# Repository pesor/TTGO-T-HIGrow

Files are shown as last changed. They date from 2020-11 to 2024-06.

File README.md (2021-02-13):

# LilyGO TTGO T-HiGrow
## TTGO T-HIGrow MQTT autodiscover interface for Homeassistant

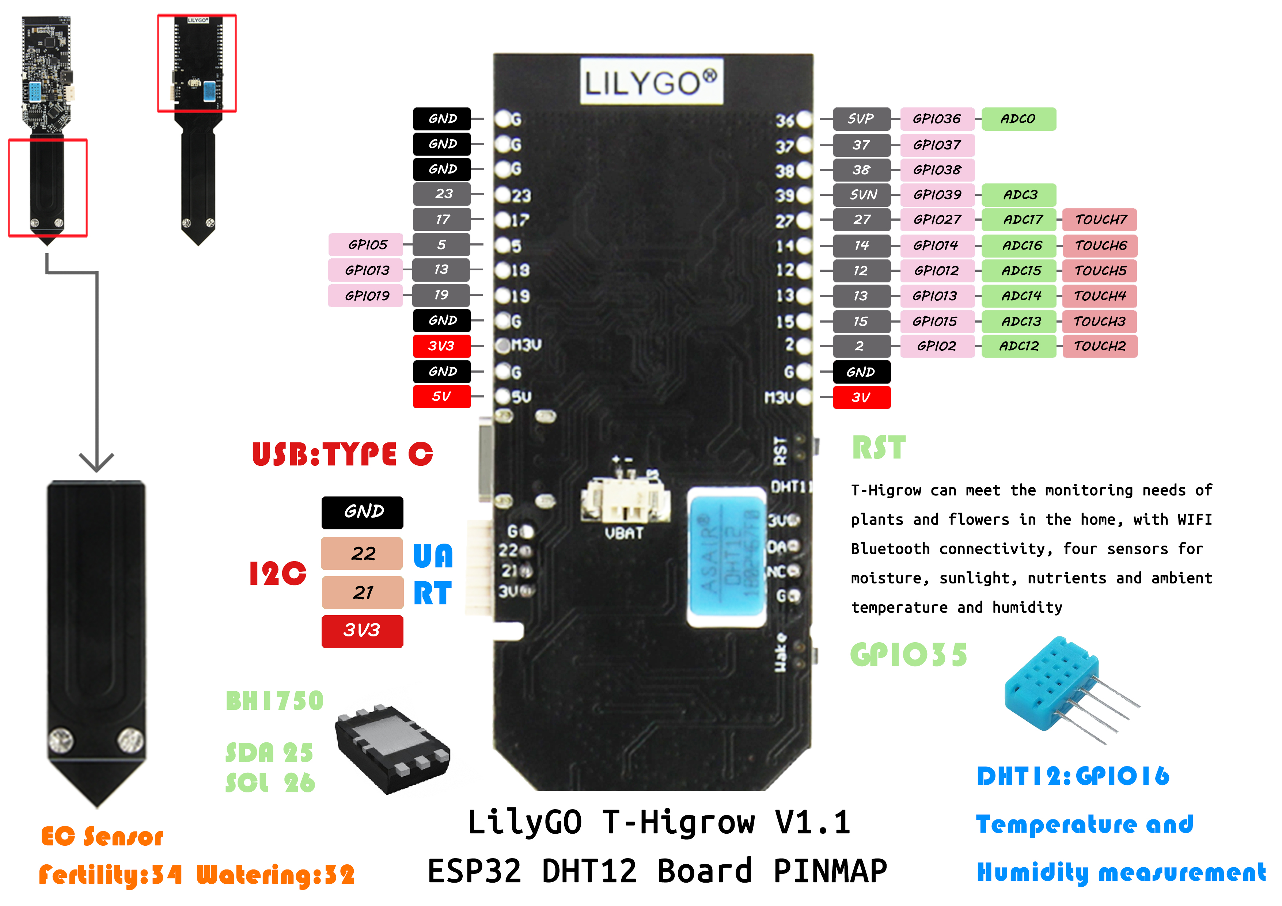
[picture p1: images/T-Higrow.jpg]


     


### Getting started

Go to the [WIKI](https://github.com/pesor/TTGO-T-HIGrow/wiki) of this Repo, there you will find a comprehensive toturial to help you implement this card.

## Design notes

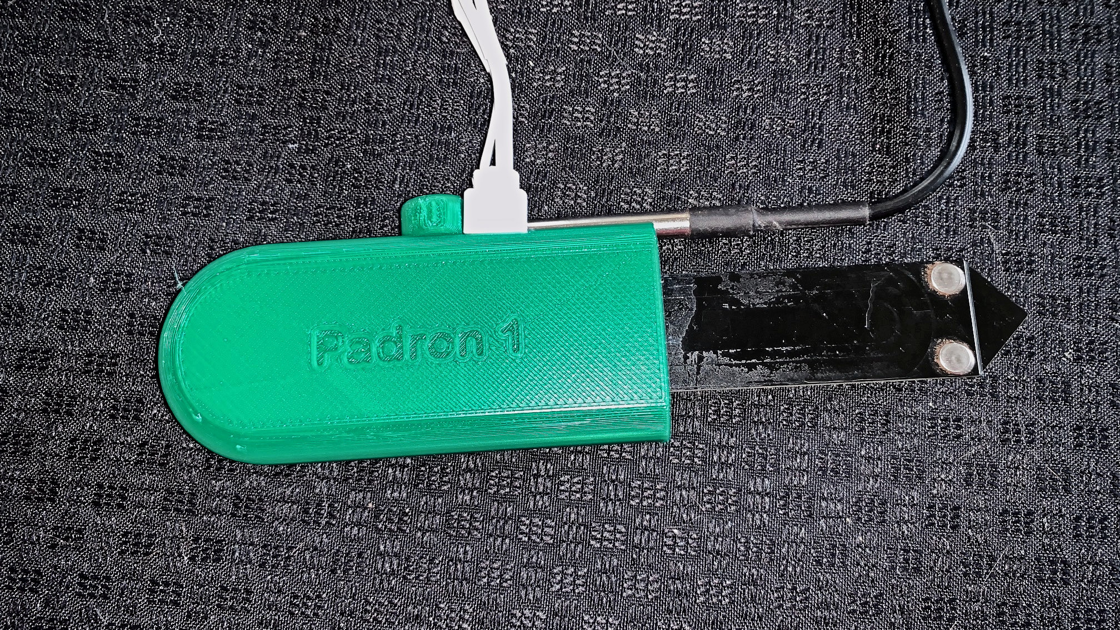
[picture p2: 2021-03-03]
images/CaseSoilTempTop.jpg

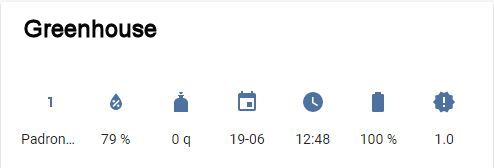
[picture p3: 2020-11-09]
images/Green-house.jpg

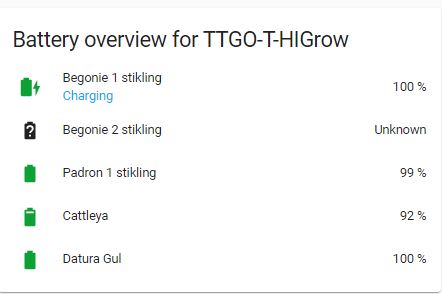
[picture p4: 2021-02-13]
images/battery-state-card-view.JPG

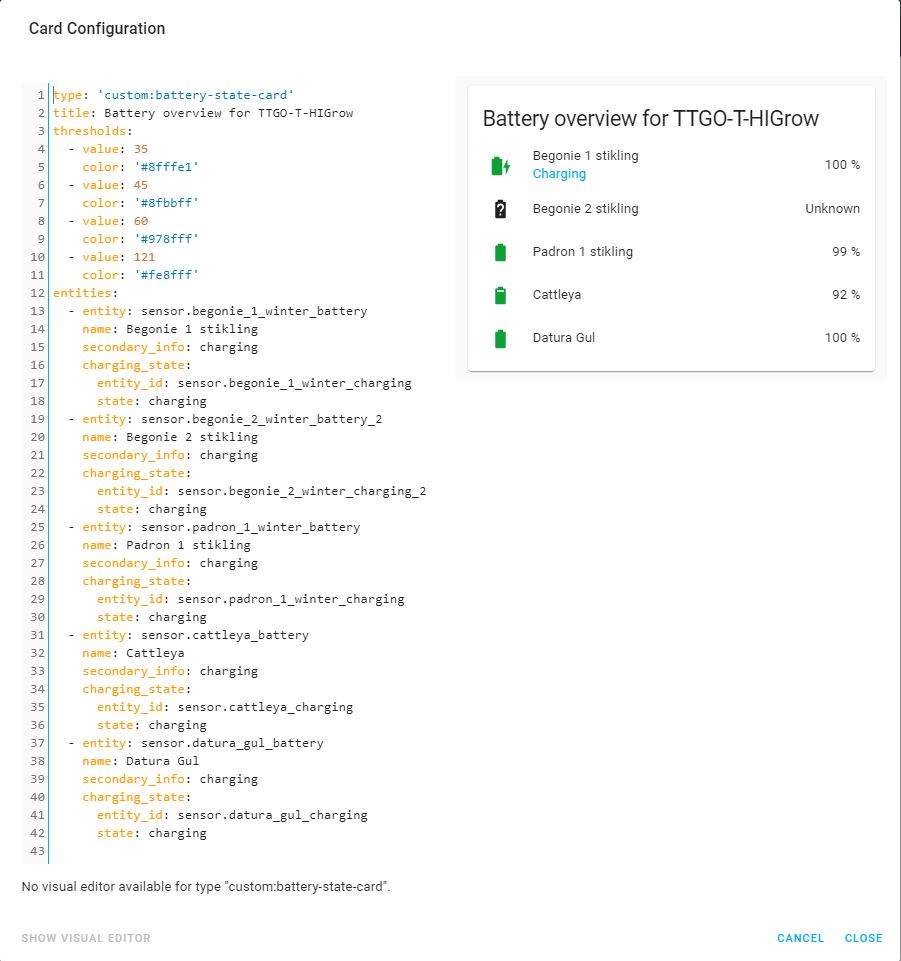
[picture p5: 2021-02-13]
images/battery-state-card.JPG

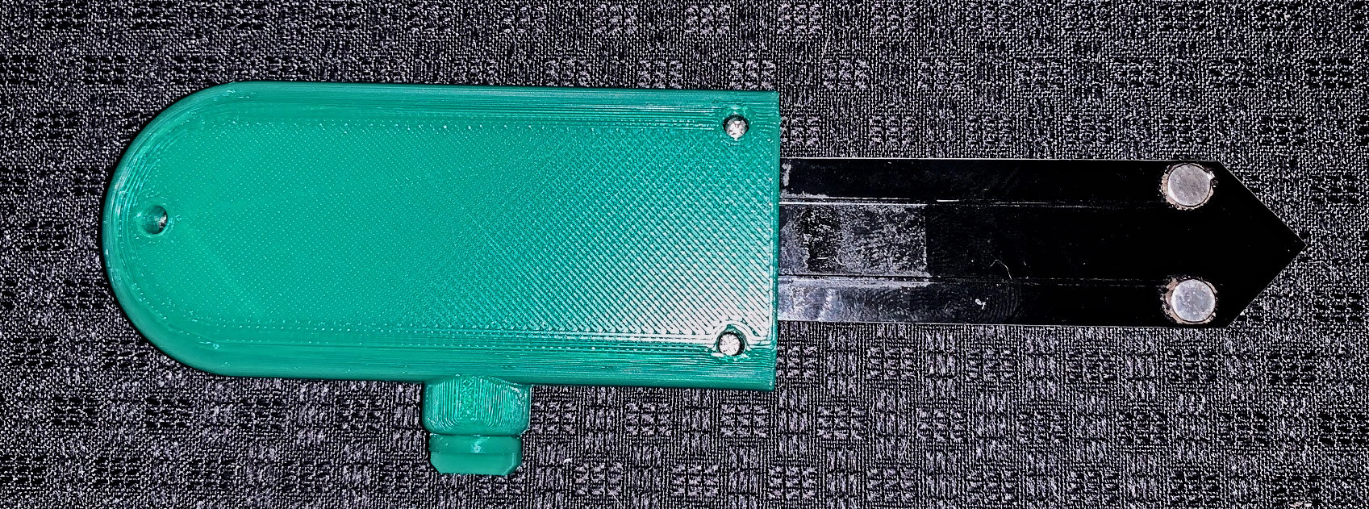
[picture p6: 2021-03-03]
images/CaseSoilBottom.jpg

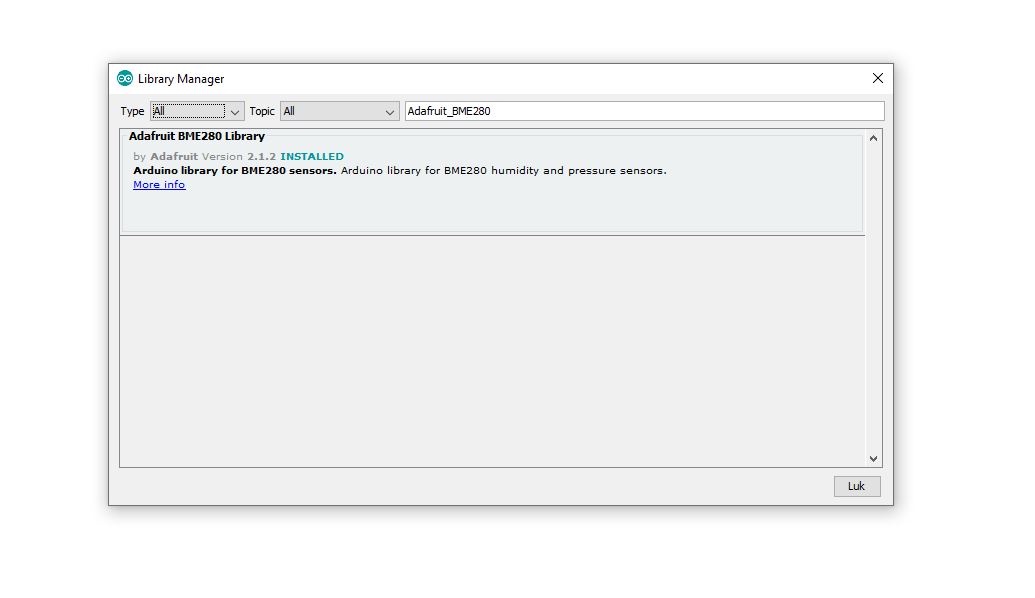
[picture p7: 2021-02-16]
images/BME280.JPG

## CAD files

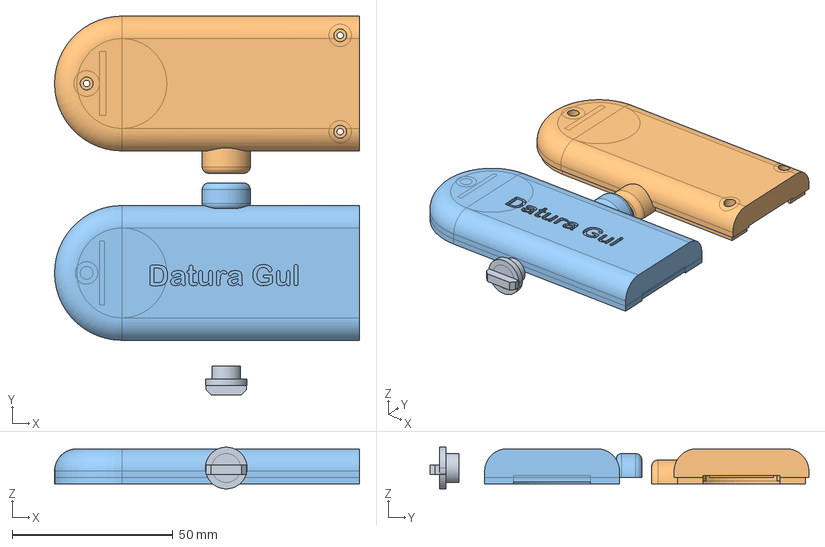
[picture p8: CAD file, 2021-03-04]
Casing/ClosedBatteryCase.FCStd
95.0 x 118.0 x 13.0 mm
Knot
Buttom
Top001

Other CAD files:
Casing/ClosedBatterySoilSensorCase.FCStd
Casing/ClosedBatteryCase.stl
Casing/ClosedBatterySoilSensorCase.stl

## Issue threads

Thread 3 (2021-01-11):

TTGO HiGrow with BME280

leeandy1, 2021-01-11:
I have just picked up 2 HiGrow boards and both have BME280 sensors onboard which are reporting null values. Both a version 1.1 boards 19-8-22.

How do I get these sensors to report values?

pesor, 2021-01-11:
There are no BME280 sensors on the boards, in the original program from LILYGO they referenced the BME280, but it is not there.

The code now have taken that into account, and therefore it will not (and cannot) report data from a nonexisting BME280.

leeandy1, 2021-01-11:
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

Thanks for the response. This is a picture of the board I have. As you can see there is no DHT11 sensor. I understand the BME280 sensor is circled in red? Please do correct me if I am wrong.

leeandy1, 2021-01-12:
Just to confirm firmware V4.0.6 appears to all function correctly for all other sensors. I currently have the board running to test battery life and will report back. I purchased the full kit with housing and battery. I am happy to assist with any testing you require but would advise I am fairly new to this.

pesor, 2021-01-12:
I will look into this.

The DHT sensor is discontinued, so I will order one with this sensor, and correct the coding to include BME280 also.

pesor, 2021-01-12:
I have just ordered on module from AliExpress, will amend coding when received.

leeandy1, 2021-01-12:
That's great to hear. If you need any help testing give me a shout.

pesor, 2021-01-12:
I also have ordered the BME280 chip it self, in order to try to solder it onto the board.

There are som confusing in the naming, some Call it BEM280, others Call it BME280, anyone knows why?

pesor, 2021-01-12:
@leeandy1 thanks for confirming, that the boards works with the soil and salt sensor.

leeandy1, 2021-01-12:
@pesor I believe it is a BME280, not sure why some people call it a BEM280 - maybe a typo?

My board has currently been running for 16 on a 200mAh battery and is reporting 97% left using your sleep settings. I need to take a look at boot count and sleep count as I think these are mixed up somehow. Boot count is 16 but sleep count is 0. Does your sleep routine effectively make the board boot each time it comes out of sleep?

pesor, 2021-01-12:
I have changed my interval to 3 hours om order to prolong the battery life.

Boot count is everytime the module starts normally after a normal deepSleep.

Sleep count, is when the module takes a 5 minutes DeepSleep, when something has gone wrong in the run. Like eg no network or mqtt connection. Zero is good, it should always be zero, otherwise the module do not run properly. The battery date counter does not work properly, I am working on that.

elecoq129, 2021-01-12:
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

On my side, I have order a pair DHT22 (white plastic packaging). I will do the soldering as soon as it arrives in replacement of the very cheap DHT11

pesor, 2021-01-12:
The DHT22 should work, if not, I will solder one (I have Them) to a module and check coding.

elecoq129, 2021-01-12:
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

I'm using the BootCount value and it works. However, the Sleep-Counter doesn't? But I'm still using an early firmware release.

elecoq129, 2021-01-12:
however I am still desperate to get the external  PT100 sensor using the DS18B20, but still missing the correct value template for mqtt broker. I have tried {{ value_json.DS18B20.Temperature }} but receive "unknow values" while all other values works. Could you please help?

pesor, 2021-01-12:
I am my self not totally sure if the sleep5counter works, as I have not yet seen a count > 0, i implemented it because I at a certain point had an unexplainable battery drain.

elecoq129, 2021-01-12:
>
>
> I am my self not totally sure if the sleep5counter works, as I have not yet seen a count > 0, i implemented it because I at a certain point had an unexplainable battery drain.

To be honest, not really needed, as bootCount is much enough

pesor, 2021-01-12:
> however I am still desperate to get the external PT100 sensor using the DS18B20, but still missing the correct value template for mqtt broker. I have tried {{ value_json.DS18B20.Temperature }} but receive "unknow values" while all other values works. Could you please help?

I do not know what you are referring to ?

leeandy1, 2021-01-12:
You can add an external sensor to the I2C UART port. I think the PT100 is just an external waterproof DS18b20 temperature and humidity sensor.

elecoq129, 2021-01-12:
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

The HiGrow board has en external (white) connector just below the USB-C, which you can connect external devices. One of them is a waterproof PT100 sensor. When I used first the code from https://github.com/Xinyuan-LilyGO/TTGO-HiGrow it worked, and used the DS18B20 in the code. That part i currently missing in yours.

pesor, 2021-01-12:
@elecoq129

please move this issue about the PT100 to a new issue, and I will look into it.

elecoq129, 2021-01-12:
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

Ok will do. More information about my project, I am growing mushroom (in France) and need crucially soil hygro information (very important to me) as well as soil temperature. Reason why I desperately need this PT100 to work as well.

elecoq129, 2021-01-12:
Last but not least, I saw your new code release v.4.0.6, very difficult to integrate it into my current code (earlier firmware version). Would it be possible for you to generate a full .ino file to be able to start a new "Arduino" install from scratch?

elecoq129, 2021-01-12:
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

> I2C UART port

Yes correct this is the device (3 different variants)

pesor, 2021-01-12:
> Last but not least, I saw your new code release v.4.0.6, very difficult to integrate it into my current code (earlier firmware version). Would it be possible for you to generate a full .ino file to be able to start a new "Arduino" install from scratch?

You will need to install VSCode and PlatformIO, as described in the Readme.

The Arduino EDI, I am no longer going to use, as the VSCode EDI, makes development and maintanance much more easy.

It is not difficult to implement, there some very good YouTube videos, that shows how to do it. Just search for VSCode and then PlatformIO, and the will popup.

elecoq129, 2021-01-12:
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

Ok I will look at it, just some more work...
Thanks for your support

pesor, 2021-01-12:
Let me know if you run into problems and I will try to help.

leeandy1, 2021-01-13:
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

Don't be scared by VSCode and PlatformIO, i'm a complete newbie to this and managed to get up and running in no time.

elecoq129, 2021-01-13:
Ok Guys you won...thanks for the encouragement. I'll do it and let you know

Get Outlook for Android<https://aka.ms/ghei36>

________________________________
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

elecoq129, 2021-01-14:
>
>
> Let me know if you run into problems and I will try to help.

Hi Pesor, I managed to install the new environment. No problem detected during compiling, flashing is ok. But here's some error error messages from the serial console?

ets Jun  8 2016 00:22:57

rst:0x1 (POWERON_RESET),boot:0x13 (SPI_FAST_FLASH_BOOT)
configsip: 0, SPIWP:0xee
clk_drv:0x00,q_drv:0x00,d_drv:0x00,cs0_drv:0x00,hd_drv:0x00,wp_drv:0x00
mode:DIO, clock div:2
load:0x3fff0018,len:4
load:0x3fff001c,len:1044
load:0x40078000,len:8896
load:0x40080400,len:5828
entry 0x400806ac
Void Setup
Listing directory: /
  FILE: /dash/favicon.ico	SIZE: 13532
  FILE: /dash/index.html	SIZE: 482
  FILE: /dash/js/app.js.gz	SIZE: 198509
- failed to open file for reading
Here comes the calibration info:

- failed to open file for reading
Here comes the name info:

- failed to open file for reading
Here comes the calibration info:

last cnt date
Size of SSID array 2
[E][WiFiSTA.cpp:124] begin(): SSID too long or missing!
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
pesor, 2021-01-17:
That is the problem,

http://homeassistant.morillesdefrance.fr

it should probably be http://morillesdefrance.fr

I do not know how it gets the homeassistant. first, unless your broker is running in a subdomain under morillesdefrance.fr.

You should check that.

elecoq129, 2021-01-17:
> http://morillesdefrance.fr
Whatever I'm trying:

morillesdefrance.fr
or
/morillesdefrance.fr
or
http://morillesdefrance.fr

below the error message

Attempting to connect to the MQTT broker: http://morillesdefrance.fr
[E][WiFiGeneric.cpp:654] hostByName(): DNS Failed for /morillesdefrance.fr
MQTT connection failed! Error code = -2
Going to sleep... 300 sekunder

pesor, 2021-01-18:
@elecoq129

Now I know what is wrong.

I tried to ping morillesdefrance.fr, and that works, I get response so no problem with the URL.

Then I took a closer look at your message when you used the IP number, and here is the explanation.

You have your mqtt broker on your LAN, which is OK, but you do not connect to it, when trying via the URL, and there is an explanation for that.

You must make a **port forward in your router** on port 1883, that refers to IP 192.168.1.47, which is your IP of your MQTT broker on your LAN.

If you do this, you open your MQTT broker for EVERYONE on the Internet, so you have to be very sure about USERID and PASSWORD, as your LAN otherwise is WIDE OPEN to the LAN.

I do not understand, why you want to use the URL, it is much safer just to use your LAN ip, as no information then is sent outside your LAN to the INTERNET (WORLD), but kept locked inside your safe LAN.

I have my MQTT broker on my Synology, and I would never address it via my URL's.

Per

elecoq129, 2021-01-18:
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

Hi Per, thanks again for you deep analyses. First of all, the reason why I want/must use an URL vs. an straight IP address is very simple: my green houses are not in the same LAN. All of them are equipped with a 4G/5G WiFi router. Thus I need to go through routing.

Of course I did set-up a port forwarding in my ISP router (I'm using the one that provides a IP fix, thus no need of using DDNS), where the mqtt server is located. And yes I have special users defined with no supervisor rights for both mqtt and HomeAssitant. In term of  configuration, I have a WIN10 PC with Ubuntu VM (Oracle) + HA as well as Synology server. For now I'm using my PC, which works well, as I'm facing issues with the hassiao & mqtt configuration with Synology. In a longer term, plan is to replace my current desktop by a mini PC dedicated (10w low consumption => https://www.aliexpress.com/item/1005001650733496.html?spm=a2g0o.cart.0.0.33373c00Yr2Dpp&mp=1)
Security wise, in a longer term, I will look at implementing some security : SSL. I'm not sure the current firmware as a module for it?
I will check later on why I can't get the mqtt connection using a URL. As said it's looks like a detail, it's very important to me.

pesor, 2021-01-18:
I understand why you need the external access. And I see that you have Security in place.

Have you tried to use the external IP in stead of the URL, not as a permanent solution, unless you as I have, Got a fixed IP.

If it works with the external IP, your problem is a DNS issue, if it does not work, I still Think that something is wrong with your port forwarding.

Do you have a firewall on the router, it can be that blocking the communication.

I understand that the router you use is the ISP’s. I NEVER do that, I only use the ISP’s router as a MODEM, and I have a Synology router to handle my Traffic.

My experience is that the ISP’s routers NEVER works optimal.

I can recommend Synology or Asus they are very good.

pesor, 2021-01-18:
Also the Security on your PC can be the reason for blocking, if your port 1883 is not open to the internet, you will not get the communication.

elecoq129, 2021-01-18:
> Also the Security on your PC, it that is running your mqtt can be the reason for blocking, if your port 1883 is not open to the internet, you will not get the communication.

Ok, I finally sorted out the issue. In my local ISP router, I was only redirecting tcp port 8123 in order to access HommeAssitant (VM). I just added another tcp port redirection 1883 and now it works. So I confirm the standard WiFi library does name resolving.

pesor,
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

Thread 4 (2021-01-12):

Battery Charge counting days not working

pesor, 2021-01-12:
I am desperately trying to get the counter for days since last charge to work, but I really have challenges for the correct update of the counter.

I am working on this.

Closed 2021-03-05.

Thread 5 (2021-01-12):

external PT100 sensor

elecoq129, 2021-01-12:
the idea is to make use of of the external I2C UART port, adding support for DS18b20 sensors would be really useful for measuring the temperature of the soil rather than the air temperature that the integrated sensor measures.
As current firmware does not use, could you please implement it?

Thanks & Regards

pesor, 2021-01-12:
You can add an external sensor to the I2C UART port. I think the PT100 is just an external waterproof DS18b20 temperature and humidity sensor. https://www.aliexpress.com/item/4000402593081.html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

Adding support for external DS18b20 sensors would be really useful for measuring the temperature of the soil rather than the air temperature that the integrated sensor measures.
I2C UART port

Added for my info.

pesor, 2021-01-13:
I have ordered the item, and will implement it when I have received Them

elecoq129, 2021-01-14:
Hi Pedro I'm planing to work tonight. Any URL to advise me for a good tuto on how to use PlatformIO IDE?

Closed 2021-03-03.

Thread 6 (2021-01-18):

Autodiscover - HowTo

pesor, 2021-01-18:
@elecoq129 **wrote**

one more question now on the autodiscovery configuration. When you say:
T_he downloaded folder Autodiscovery, you copy to Home Assistant config folder (where you have your configuration.yaml)__

Do you mean copy the contents of the autodiscovery into config from HomeAssistant or you have to create also the directory structure and the files?

pesor, 2021-01-18:
@elecoq129

Actually, the placement of the autodiscover folder, can be of your own choice, as it sadly can not run inside Home-Assistant .

You need to have the sensors folder, and the sensor.yaml in that folder.

In the sensor.yaml, you erase all but the first 4 lines, and a blank 5th line.

You run the TTGO-T-HIGrow-aut.py, as you normally would run a Python script.

I use the EDI - Eric6, that is a fantastic Python EDI.

pesor, 2021-01-18:
@elecoq129 **Wrote**

I assume that You have to run the aut.py script in the win10 machines that runs HomeAssistant?
If I manyuall chage the mac information in the sensor.yaml, that would not be enough for HomeAssistant to get the information from the sensor?

pesor, 2021-01-18:
The TTGO-T-HIGrow-aut.py script do more than just update the sensors file, it actually initiate the modules into Home-Assistant.

If you change in the sensors.yaml file manually, it will not be registered by the Home-Assistant, and you will not get your information there.

As you started from an earlier release, you already there made the sensors in the configuration.yaml file, you can continue doing that, but it is a pain to maintain all those entities in the configuration.yaml, and you miss a lot of automations issue, which your get via the user interface, when doing the autodiscover.

If you do not have Python installed in your Windows10 you must do it, as with the VSCode and PlatformIO, YouTube have a lot of videos showing how to do it. You do not need programming skills, only the need to run a Python Script from time to time.

The Eric6 EDI, is just like a normal text editor, it just supports Python, and makes it possible for you to run the script within Windows10.

elecoq129, 2021-01-18:
I have installed Eric Python, when I execute the script it comes up with the error with missing YAML package.
Do you have any idea which one and how to install it?

elecoq129, 2021-01-18:
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

I have Visual Studio Code and PlatformIO up&running much easier than Arduino...

elecoq129, 2021-01-19:
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

I understand you're fan of Eric's stuff. However, I'm still struggling just to install the environment. Especially the YAML into it.
For information I spent hours to try to install Ubunto shell with YAML on the same machine that already runs HA + mqttt under Oracle VM: issue there is a conflict between them. Virtual box is actually locking (at the bios level) the Virtualization capability.

Can you please recommand a URL for a good tuto to install both products
 on a WIN10 platform?

pesor, 2021-01-19:
@elecoq129
———
Especially the YAML into it.
For information I spent hours to try to install Ubunto shell with YAML on the same machine
———
I really do not understand what you are doing, yaml and Python,ubunto, does not give any meaning to me.

I will send you links to what is necessary, but I can first do it tomorrow.

So hang on, we will make it work.

Per

elecoq129, 2021-01-19:
Thanks then I can get some sleep tonight 👍

pesor, 2021-01-20:
@elecoq129 @BeardedTinker

In order to get Autodiscovery to work, you must install Python3 on Windows10.

This is the link for for installing Python3 in windows.:

https://phoenixnap.com/kb/how-to-install-python-3-windows

Then you can install Eric6 from this link:

https://sourceforge.net/projects/eric-ide/files/eric6/stable/

You download the zip file, and unpack it to a location of your choise.

You then have to start a CMD (Commando promt) and change directory/folder to where you have unpacked Eric6

You then follow this:

Windows
Download the 64-bit variant of Python 3 available at python.org and install it.
Extract the downloaded eric distribution archive (see above) to a temporary location and execute the install.py script.
(**Your directory for the unpacked Eric6) and write python.exe install.py**).
Note: If some pre-requisite Python packages are not available, the script will ask for permission to install the missing one.
Optional: If Qt development is desired, the respective tools need to be available. This requires the installation of the Qt toolkit using these steps.

(for me it installed QT automatically, but if not  follow this)
Download the Qt online installer from the Qt download site.
Install Qt by executing the installer.
Configure the path to the Qt tools on the Qt page of the eric configuration dialog.
Note: The Qt development tools may be installed with the command C:\Python39\Scripts\python.exe -m pip install qt5-applications instead.

Hope this helps you.

Per

elecoq129, 2021-01-20:
thanks Per for your instructions, I was looking for it.
I think I will create a new Win VM in order to install those, as I have a bad feeling with my current Windows environment.
(it looks like I screw up a bit of things there...) I am desperate to get this last phase up-and-tuning.

Cheers
Emmanuel

pesor, 2021-01-20:
Glad to be able to help.

This is where @BeardedTinker is much better than me, I mean to get things explained understandablely from the start.

Hope this will make the success for you, otherwise do not hesitate to ask.

Per

elecoq129, 2021-01-20:
So I followed all your installation steps above at the exception of Qt, as the package is currently not available for download (major hard disk crash in the cloud, not even the mirror sites are up). But I assume that I don't really need it?
I assume from there you execute the script directly from the (windows) Eric app. that has ben installed?

pesor, 2021-01-20:
Correct, good luck :-D

elecoq129, 2021-01-20:
I got an error during executing the script:
Line 831: sock.connect(sa)

Could you help?

pesor, 2021-01-20:
I need to see some output, and where do you get the error, which program?

elecoq129, 2021-01-20:
After I ran the autodiscovery program, here's what I get:
the program has terminated with an exit status 0.
Is this OK, as I seems that I do not get anything to the sensors. yaml ?
So I'm not able to pick any entities for the sensor?

pesor, 2021-01-21:
@elecoq129

This is not correct, the program should not stop,

below is my output when running the program, with all sensors known:.

With unknown sensors, there will be much more information, as it is sent to Home-Assistant.

With an exit 0, something is wrong, what is the output from the program, can you send that?

Output from program:
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
pesor, 2021-01-21:
Should not have marked at programming, as this issue program then do some formatting, here is the raw text:

'''
TTGO-HIGrow to MQTT Gateway, release 3.0.0
'''
import json
import yaml
import paho.mqtt.client as mqtt

# Configuration File Locations

SENSORS_FILE = "sensors/sensors.yaml"

# Write data to YAML file
def write_yaml_file(mac_id,  name):
    print("in write_yaml_file")
    sensors = dict()
#    print("after dict")
    sensors['mac_id'] = mac_id
    sensors['name'] = name

So remove the #

pesor, 2021-01-21:
Now I am really pi....d, try again with a picture

pesor, 2021-01-21:
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

Here is it readable

pesor, 2021-01-21:
make sure to make the lining correct, the print, must be in line with sensors - print - sensors, there must be no indentation here

elecoq129, 2021-01-21:
can please tell exactly which program? main.ccp?

elecoq129, 2021-01-21:
ok fund it this is within the script

pesor, 2021-01-21:
Thats correct, the TTGO module programs are functioning correctly

elecoq129, 2021-01-21:
Here's the first one
![Uploading script error 1.jpg…]()

pesor, 2021-01-21:
I don’t see the jpg file

elecoq129, 2021-01-21:
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

pesor, 2021-01-21:
It was only the # in front of print you should remove.

pesor, 2021-01-21:
Invalid syntax in Eric means that you have removed a # you should not have.

elecoq129, 2021-01-21:
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

You're right I had removed too much.
Started again with your genuine file, removed all "Print":
it always comes-up with the same error

pesor, 2021-01-21:
You need to place a # in front of the text in the red Line, it is a comment and not a program line

elecoq129, 2021-01-21:
yes I saw. here we go what we get now
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

pesor, 2021-01-21:
Every time you see the “bug” you have removed a # you should not have removed.

pesor, 2021-01-21:
I an 99 percent you do not get access to your MQTT server, have you tried with the ip in stead of the URL, and are you using port 1883.

elecoq129, 2021-01-21:
>
>
> I am 99 percent sure you do not get access to your MQTT server, have you tried with the ip in stead of the URL, and are you using port 1883.

Yes my current configuration is back with the IP address

pesor, 2021-01-21:
Can I see the part of the program with the mqtt info

pesor, 2021-01-21:
Please, do not use VSCode, the problem is ONLY in the Python script in Eric6

So in the Python script I would like to see your mqtt info.

pesor, 2021-01-21:
Are you giving username and password in the Python script?

elecoq129, 2021-01-21:
> Are you giving username and password in the Python script?

No I don't.
Should I?

elecoq129, 2021-01-21:
> Please, do not use VSCode, the problem is ONLY in the Python script in Eric6
>
> So in the Python script I would like to see your mqtt info.

Which part?

elecoq129, 2021-01-21:
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

elecoq129, 2021-01-21:
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

Ok here we go the IP address is wrong here

pesor, 2021-01-21:
If you do not give username and password in the Python script, you will be rejected from the MQTT server, just like any other login.

By default I have not given my MQTT server password as it only is acessable from my Lan.

The mqtt info is at the bottom of the script.

forget the socket.py script, it is a library script, and only gives errors when something is wrong in the Autodiscovery script I have made.

elecoq129, 2021-01-21:
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

we are getting there

pesor, 2021-01-21:
Look at the Line over client.Connect and renere the # and then write the username and password. Fingers crossed.

elecoq129, 2021-01-21:
ok just did

client.connect("192.168.1.165", 1883, 60)
What is the last value: 60?

elecoq129, 2021-01-21:
![Uploading working script but not filling sensors.yaml file.jpg…]()

elecoq129, 2021-01-21:
Where should I read/get the value information?
In the sensors.yaml (local) file right?

pesor, 2021-01-21:
You have not removed the #

elecoq129, 2021-01-21:
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

youre gonna like this one!

elecoq129, 2021-01-21:
But the sensors file still empty :(

pesor, 2021-01-21:
Succes 👍.

You have had a ruf time, thanks for not giving up.

I very
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

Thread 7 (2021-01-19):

4.0.6 - Arduino --> VSCode and PlatformIO

pesor, 2021-01-19:
@ericsebastion **WROTE**

> just purchased the BME280 version and i cant find where to download the arduino file for this new 4.x version I was redirected to. I used the old version and the soil part shows up as working in the serial monitor but the mqtt wont connect and I don't see the temp and humid readings. Any help would be appreciated. I'm trying to use this in Home Assistant also if that helps clarify.

pesor, 2021-01-19:
I did abandon the Arduino EDI for practical reasons.

I have changed to VSCode and PlatformIO, as this platform is much easier to maintain, and do development in.

You will have to install VSCode and PlatformIO, in order to run version 4.x.x.

On YouTube there is very good instructions on how to do this, just search for VSCode and PlatformIO, and it should go very easy to install it, and after it is installed, it is like using any text editor, this is just preperet for C++, and it is very easy to compile and get the programs to the module.

Don't hesitate to ask questions in this thread, I will answer fast.

pesor, 2021-01-19:
@BeardedTinker

Maybe it is soon time for a video for the 4.x.x installation, with an inclusion for the VSCode and PlatformIO

;-)

pesor, 2021-01-19:
I came by this video, it is about 3D firmware update, but there are a chapter where he explains how to install VSCode, and another chapter for the PlatformIO.

All the rest you just skip.

https://www.youtube.com/watch?v=eq_ygvHF29I

BeardedTinker, 2021-01-19:
> @BeardedTinker
>
> Maybe it is soon time for a video for the 4.x.x installation, with an inclusion for the VSCode and PlatformIO

It's overdue already! I hope, if all goes as planed, to have it done in first week of February. Kids should be back in school then (real not online) and I'll have a bit more time then.
I'm really guilty for this one 😁

ericsebastion, 2021-01-19:
@BeardedTinker looking forward to it!

elecoq129, 2021-01-20:
If I may a comment to BeardeTinker, as there is a large of o tuto for installing VSCode/PlattformIO (https://randomnerdtutorials.com/vs-code-platformio-ide-esp32-esp8266-arduino/) I would rather prefer you'll work on a tuto to install the necessary stuff (Eric + Python) in order to run the Autodiscovery part. That would me usuful!
It's just an idea...

Closed 2021-03-03.

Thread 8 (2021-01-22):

4.x.x integration HA on Raspberry PI

pesor, 2021-01-22:
@ericsebastion

Lets start with the basics.

You are running Home Assistant on Raspberry PI!
Which version of PI?

Do you have a mqtt server running on the Raspberry PI?

Do you have a Windows10 PC, as a workstation?

This is 3 crucial questions - I need answer for, to proceed.

ericsebastion, 2021-01-24:
I have a Raspberry Pi 4+ and using Mosquito Broker for my MQTT. Im using a Windows 10 to do my code work and flashing of other ESP32s i have for my grow tent.

Thanks!

pesor, 2021-01-25:
This is what I expected.

You then only need to use Windows10 to do all the implementation about the TTGO-T-HIGrow.

You need to have VSCode and PlatformIO installed, there is a good tutorial video in the issue about VSCode and PlatformIO.

You need to install Python for Windows10, and Eric6, there is a documentation made by Emmanuel, in the Repo Code section.

Then you should be ready to start running.

Start with the modules, and use MQTTlens, to see the output from the modules on your mqtt server(broker)

You will not see any modules in HA, until autodiscover, but that is ALL as it should be.

When you have that up and running, and see the messages in MQTTlens, we go to the autodiscover part.

//Per

pesor, 2021-01-25:
@ericsebastion

I just reread my above note, and it could be read as you are on your own on the first part.

This is not the case, when doing the first part, just ask as many questions as you need, I will be there.

//Per

Closed 2021-03-03.

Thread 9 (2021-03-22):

Core panic

crsprsp, 2021-03-22:
My Board tells me:
---------------
SSID name: HelloG............
Connected to network
0C:9E:9D:9B:92:9C
10.10.17.6
IN VINTERTIME
Wire ok
Could not find a valid BMP280 sensor, check wiring!
BH1750 Advanced begin
lux 27.50
0
Soil before map: 3523
Guru Meditation Error: Core  1 panic'ed (IntegerDivideByZero). Exception was unhandled.
-----------------
And reboots.
Tried with another (new) Board but it's the same.

pesor, 2021-03-22:
Are you on 4.3.1

crsprsp, 2021-03-23:
Yes, i am. Also downloaded the V4.3.1 again and uploaded it again. Same behavior.

pesor, 2021-03-23:
You are getting a division by zero error,
It is something in your user settings, I thing

Have you made the BME variable false?

I need your user-variables file, remember to remove your passwords.

check main.cpp for the following

const String rel = "4.3.1"; // Finally the days since last charging works correctly.

// mqtt constants
WiFiClient wifiClient;
PubSubClient mqttClient(wifiClient);

// Date calculator
unsigned long epochTime;
String battChargeEpoc;
unsigned long epochChargeTime;
float battChargeDateDivider = 86400;

The battChargeDateDivider must be 86400

crsprsp, 2021-03-23:
ok, here we go:

// *******************************************************************************************************************************
// START userdefined data
// *******************************************************************************************************************************
#include <Arduino.h>
// Turn logging on/off - turn read logfile on/off, turn delete logfile on/off ---> default is false for all 3, otherwise it can cause battery drainage.
const bool  logging = false;
const bool  readLogfile = false;
const bool  deleteLogfile = false;
String readString; // do not change this variable

// Select DHT type on the module - supported are DHT11, DHT12, DHT22 -- Even if you do not have one, you have to uncomment one, as compilation else will fail.
#define DHT_TYPE DHT11
//#define DHT_TYPE DHT12
//#define DHT_TYPE DHT22

// Set to true if you have a DHT sensor on the board, and false if not
bool dht_found = true;

// Select if 18B20 soil temp sensor available, if available -->> set to true
const bool USE_18B20_TEMP_SENSOR = false;

// It is a really good thing to calibrate each unit for soil, first note the number when unit is on the table, the soil number is for zero humidity. Then place the unit up to the electronics into a glass of water, the number now is the 100% humidity.
// By doing this you will get the same readout for each unit. Replace the value below for the dry condition, and the 100% humid condition, and you are done.

// Soil defaults - change them to your calibration data
int soil_min = 1535;
int soil_max = 3300;
bool calibrate_soil = false;

// Salt/Fertilizer recommandation break points. You can change these according to your own calibration measurements.
int fertil_needed = 200;
int fertil_low = 201;
int fertil_opt = 251;
int fertil_high = 351;

// Give the sensor a plant name, change to true, upload sketch and then revert to false
const bool update_plant_name = true;
String plant_name = "Tomato";

//If using the Greenhouse automatic watering repo, then assign a waterValveNo to the plant.
int plantValveNo = 1;

// define your SSID's, and remember to fill out variable ssidArrNo with the number of your SSID's
String ssidArr[] = {"ThisIsMyWireless" };
int ssidArrNo = 1;

const char* ssid = ""; // no need to fill in
const char* password = "My1Passwo4D";
const char* ntpServer = "pool.ntp.org";

// Off-sets for time, and summertime. each hour is 3.600 seconds.
const long  gmtOffset_sec = 3600;

// Device configuration and name setting
const String device_name = "Tgrow_HIGrow"; // Can be changed, but not necessary, as it will give no added value.

#define uS_TO_S_FACTOR 1000000ULL //Conversion factor for micro seconds to seconds
#define TIME_TO_SLEEP  10800       //Time ESP32 will go to sleep (in seconds)

const char broker[] = "my.broker.com";
int        port     = 1883;
const char mqttuser[] = "ThisUser"; //add eventual mqtt username
const char mqttpass[] = "ThisPassword1"; //add eventual mqtt password

crsprsp, 2021-03-23:
And to be complete a snipplet from the monitoring output of the vcode:

SSID name: ThisIsMyWireless.
Connected to network
7C:9E:BD:FB:F1:90
192.168.10.54
IN VINTERTIME
Wire ok
Could not find a valid BMP280 sensor, check wiring!
BH1750 Advanced begin
lux 30.00
0
Soil before map: 3729
Guru Meditation Error: Core  1 panic'ed (IntegerDivideByZero). Exception was unhandled.
Core 1 register dump:
PC      : 0x40163751  PS      : 0x00060c30  A0      : 0x800d1a0c  A1      : 0x3ffcab80
A2      : 0xfffa4f5c  A3      : 0x00000000  A4      : 0x00000000  A5      : 0x00000064
A6      : 0xffffff9c  A7      : 0x00000001  A8      : 0x00000000  A9      : 0x3ffcab60
A10     : 0x00000002  A11     : 0x00000e91  A12     : 0x0000000a  A13     : 0x00000000
A14     : 0x0000011e  A15     : 0x3ffc2494  SAR     : 0x0000001c  EXCCAUSE: 0x00000006
EXCVADDR: 0x00000000  LBEG    : 0x400014fd  LEND    : 0x4000150d  LCOUNT  : 0xffffffff

ELF file SHA256: 0000000000000000

Backtrace: 0x40163751:0x3ffcab80 0x400d1a09:0x3ffcaba0 0x400d3817:0x3ffcabc0 0x400daca6:0x3ffcace0 0x40091272:0x3ffcad00

Rebooting...
ets Jun  8 2016 00:22:57

rst:0xc (SW_CPU_RESET),boot:0x13 (SPI_FAST_FLASH_BOOT)
configsip: 0, SPIWP:0xee
clk_drv:0x00,q_drv:0x00,d_drv:0x00,cs0_drv:0x00,hd_drv:0x00,wp_drv:0x00
mode:DIO, clock div:2
load:0x3fff0018,len:4
load:0x3fff001c,len:1044
load:0x40078000,len:10124
load:0x40080400,len:5828
entry 0x400806a8
Void Setup
Listing directory: /
  FILE: /name.conf      SIZE: 6
- failed to open file for reading
Here comes the calibration info:

Writing file: /name.conf
- file written
- failed to open file for reading
Here comes the charge date info info:

Size of SSID array 1

SSID name: ThisIsMyWireless.............
Connected to network
7C:9E:BD:FB:F1:90
192.168.10.54
IN VINTERTIME
Wire ok
Could not find a valid BMP280 sensor, check wiring!
BH1750 Advanced begin
lux 30.00
0
Soil before map: 3728
Guru Meditation Error: Core  1 panic'ed (IntegerDivideByZero). Exception was unhandled.
Core 1 register dump:
PC      : 0x40163751  PS      : 0x00060c30  A0      : 0x800d1a0c  A1      : 0x3ffcab80
A2      : 0xfffa4fc0  A3      : 0x00000000  A4      : 0x00000000  A5      : 0x00000064
A6      : 0xffffff9c  A7      : 0x3ffc8da0  A8      : 0x00000000  A9      : 0x3ffcab60
A10     : 0x00000002  A11     : 0x00000e90  A12     : 0x0000000a  A13     : 0x00000000
A14     : 0x00000020  A15     : 0x3ffc2494  SAR     : 0x0000001c  EXCCAUSE: 0x00000006
EXCVADDR: 0x00000000  LBEG    : 0x400014fd  LEND    : 0x4000150d  LCOUNT  : 0xffffffff

ELF file SHA256: 0000000000000000

Backtrace: 0x40163751:0x3ffcab80 0x400d1a09:0x3ffcaba0 0x400d3817:0x3ffcabc0 0x400daca6:0x3ffcace0 0x40091272:0x3ffcad00

Rebooting...
ets Jun  8 2016 00:22:57

pesor, 2021-03-23:
I just took a bright new board, and tried to flash the board.

I get exact the same error as you.

Somehow, the current users have used boards with earlier versions of the firmware on them, and then avoid the error.

I will look into it immediately.

crsprsp, 2021-03-23:
perfect! glad you could reproduce the error! If you need extended testing, please gimme a sign!

pesor, 2021-03-23:
So, I found the reason, and I found a bypass..

Set the **bool calibrate_soil = true;**

it then writes the file, and you can change to false again, and change again to true, when you do the actual calibration, and then remember to set to false, when calibration has been done.

When the file do not exists, it creates a **division by zero error** in the program, this is the reason.

I will make a proper fix later.

pesor, 2021-03-23:
Thanks, but I know what is wrong, so I just need the time to program the fix.

In the meentime use the worksround in order to use the firmware.

Sendt fra min iPhone

Den 23. mar. 2021 kl. 16.30 skrev crsprsp ***@***.***>:

perfect! glad you could reproduce the error! If you need extended testing, please gimme a sign!

—
You are receiving this because you commented.
Reply to this email directly, view it on GitHub<https://github.com/pesor/TTGO-T-HIGrow/issues/9#issuecomment-804999399>, or unsubscribe<https://github.com/notifications/unsubscribe-auth/AAXXLJCSJOAINMYJTIM2YDLTFCXY7ANCNFSM4ZTKBRWQ>.

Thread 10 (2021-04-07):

Autodiscover in Raspi 4

front0708, 2021-04-07:
Hi pesor,

thank you fpr the whole wiki.

I really like to bring it to work on a my raspiberry pi. I studied again and again the youtube vids and the Wiki. It all works fine for me. The sensor is connecting to the MQTT broker und publishes the message succesfully. And then I stop because I don't know how to execute the "TTGO-T-HIGrow-aut.py" via python.

- Via putty: There ist no python to start on raspi for starting the "TTGO-T-HIGrow-aut.py"

 - Via Add-On "Visual Studio Code" in Homeassistant: There is the wrong python-version and therefore no paho-mqtt.

 - Via eric IDE I don't know how to start the "TTGO-T-HIGrow-aut.py" on raspi, Home Assistant from the WIN 10 Eric IDE

I really don't want to throw the towel after those hours of trying and i'm very interested in getting things done. Can you please tell me, how to do it in raspi or is it not possible. When it is the second point, can you tell me whre to find how to integrate the sensor manually in home assistant?

Thank you so much. Up to this point, I am very disappointed. If you can help me, It woul be a pleasure for me.

front0708

ivanling, 2021-04-10:
Hi,
I have the exact same problem. I have put TTGO-T-HIGrow-aut.py inside /python_scripts and sensors.yaml inside /python_scripts/sensors.yaml. Now I see Python Scripts: ttgo-t-higrow-aut in developer-tools/service ,the service dev tool allows you to call any available service in Home Assistant. But after that my sensor.yaml remains unchaged, and if I see Home Assistant log I have:

2021-04-10 23:07:29 ERROR (MainThread) [homeassistant.components.websocket_api.http.connection] [548366779392] Error handling message: Service python_script.ttgo-t-higrow-aut does not match format <domain>.<name> for dictionary value @ data['sequence'][0]['service']. Got 'python_script.ttgo-t-higrow-aut'

Any idea?

Thanks

pesor, 2021-05-15:
Sorry for not answering earlier, I am right now very busy with my Greenhouse project and have not seen your input.

First of all, the program cannot run inside Home Assistant, as Home Assistant do not support the file reading of the sensors.yaml.

It is a simple Python script, which should run in any Python environment.

You just have to address same mqtt server as Home Assistant, and the sensors.yaml should be accessed from the Autodiscover.py.

The Autodiscover.py is completely Independent of Home Assistant, it just follows the Home Assistants Autodiscover routines.

So if you can run any Python script on your Raspberry, you just run Autodiscover.py same way, and it should work.

Again, do not try to run it via Home Assistant, it will NEVER work, as some of the features are not supported by Home Assistants build in service protocol.

pesor, 2021-05-15:
Found this for installing Eric in Raspberry PI, maybe it will help.

https://github.com/REDUNION/eric_ide_on_raspberry_pi_4

ivanling, 2021-05-15:
Hello, Thanks for your answers. I have postponed switching to Linux, my entire digital life was Windows, but now I wanted to take this opportunity to learn and develop for home assistant to also develop the domain of competencies in Linux-based OS.
I already have Lubuntu 18.04 running in a ASUS EEE 1000H, and have managed to made an installation of HA, in python virtual environment. As soon as I have some time I go try to make things work with your firmware and with help of
BeardedTinker tutorial

Thanks a lot

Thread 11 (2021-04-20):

*** [.pio\build\esp32dev\src\main.cpp.o] Error 1

erikvtv, 2021-04-20:
Hi Pesor,

When I use PlatformIO to upload and monitor my TTGO- T-HIGROW it generates an error
I have attached the logging of the error.

Do you have any idea what could the problem?

Is there away to clean or remove files from esp32dev?

Regards,
Erik
[error - upload and monitor.txt](https://github.com/pesor/TTGO-T-HIGrow/files/6346352/error.-.upload.and.monitor.txt)

erikvtv, 2021-04-22:
got it resolve

Closed 2021-04-22.

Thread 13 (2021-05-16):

In code remarks You're wondering what "Salt" is

wagnerohz, 2021-05-16:
The sensor measures the conductivity of the earth between the two shiny silver buttons. This is an indication of the amount of dissolved salts that the plants need as food. These values can only be approximations. And they only make sense if the soil is moist. The limit values for "needed", for example, seem to me to be set too high.
I measured once:
- Fresh rainwater has 0 (measured value: 30µS)
- Tap water has 78 (measured value: 588 µS)
- Water with liquid fertiliser according to the manufacturer's instructions: 371 (measured value: 4000 µS)
The values of the sensor are fairly linear.

This is not a criticism of your magnificent work, just a (perhaps) helpful addition.

pesor, 2021-05-16:
Yes the salt figure is a tricky part.

The tap water here in Denmark is filled with calcium, at my House the DH is > 26, the salt measurement in clean tap water in a glass is approx. 200.

It is possible in uservariables to set the salt levels, so that it comply with your needs.

I actually did an (not released yet) addition to the salt issue, where the figure was divided with the soil level/100, and a treshold for when calculation should start, eg >60% soil.

It is giving me a division be Zero error sometimes, so I will look into it, and add it to next release.

I am currently working on a special HIGrow Lovelace card, but that is to be in a much later release.

Also there is a bug in the measurement, as it is done with DC current and not AC current, this means that the measurement will detoriate over time, if you do not make sure that your watering flushes the sensor.

The DC current organise the ION's so that they are placed in ION- to one side and ION+ to the other side, which makes the measurement going toward zero.

//Per

wagnerohz, 2021-05-16:
Thank you very much for the detailed engagement with my reflections. Yes, we have 6-7° DH here in my place in northern Germany. Now I understand why the threshold values in your code are suggested so high.
Thank you for the important hint with the "sorting" of the ions at the anodes. I had also noticed that the values dropped faster than my test plants could "drink". I will observe the flushing of the sensor.

I am very curious about your next releases.

//Christian

pesor, 2021-05-16:
Hi Christian.

I have been working with a better presentation of the most important data from the sensor.

As I wrote I am trying to make a Lovelace card, but I have at this moment an intermidiate solution you might like.

I did send this to Bearded Tinker, with whom I communicate a lot.

————————-

This is the latest on my TTGO-HIGrow sensor output for my plants.

I have put development of a better card on hold, as I have too many things on my hand at the moment, so I figured this is a good intermediate solution.

I have included a screen shot, and the code for the “Drivhusplanter”, which is the most comprehensive.

Here are the HIGrow info.

[cid:6C21789F-894D-4A77-A1F4-83F47C5CEE5D]

Here are the code:

type: entities
title: Drivhusplanter
entities:
  - entity: sensor.padron_1_battery
    name: Padron 1
    type: 'custom:secondaryinfo-entity-row'
    secondary_info: >-
      <b style='color:red'> Last updated: [[ sensor.padron_1_date ]] at [[
      sensor.padron_1_time ]] <br> On battety: [[ sensor.padron_1_daysonbattery
      ]] days <br> Last charged: [[ sensor.padron_1_batchargedate ]]</b>
  - entity: sensor.padron_1_soil
    name: ' '
    type: 'custom:secondaryinfo-entity-row'
    secondary_info: >-
      <b style='color:green'> Gødningstilstand: [[ sensor.padron_1_fertilizer ]]
      <br> Jordtemperatur: [[ sensor.padron_1_soiltemp ]] <br>
      Drivhustemperatur:  [[ sensor.padron_1_temperature ]] </b>
  - entity: sensor.padron_3_battery
    name: Padron 3
    type: 'custom:secondaryinfo-entity-row'
    secondary_info: >-
      <b style='color:red'> Last updated: [[ sensor.padron_3_date ]] at [[
      sensor.padron_3_time ]] <br> On battety: [[ sensor.padron_3_daysonbattery
      ]] days <br> Last charged: [[ sensor.padron_3_batchargedate ]]</b>
  - entity: sensor.padron_3_soil
    name: ' '
    type: 'custom:secondaryinfo-entity-row'
    secondary_info: >-
      <b style='color:green'> Gødningstilstand: [[ sensor.padron_3_fertilizer
      ]]</b>

You need to install card-tools.js, and secondaryinfo-entity-row via HACS, read more here: https://github.com/custom-cards/secondaryinfo-entity-row

————————-

Best regards,
Per

Sendt fra min iPhone

Den 16. maj 2021 kl. 14.43 skrev wagnerohz ***@***.***>:

Thank you very much for the detailed engagement with my reflections. Yes, we have 6-7° DH here in my place in northern Germany. Now I understand why the threshold values in your code are suggested so high.
Thank you for the important hint with the "sorting" of the ions at the anodes. I had also noticed that the values dropped faster than my test plants could "drink". I will observe the flushing of the sensor.

I am very curious about your next releases.

//Christian

—
You are receiving this because you commented.
Reply to this email directly, view it on GitHub<https://github.com/pesor/TTGO-T-HIGrow/issues/13#issuecomment-841811978>, or unsubscribe<https://github.com/notifications/unsubscribe-auth/AAXXLJC6WR2CN7F3ZD5UPZTTN64WRANCNFSM446UYN7Q>.

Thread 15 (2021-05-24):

Battery consumption issue, temporary fix.

pesor, 2021-05-24:
This change will come in a later release, but I think you should correct your code, and upload it next time you charge a battery from a module.

This is the original code in the main.cpp
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

Change it to:
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

I discovered this when due to the DDoS attach at one of the biggest ISP’s here in Denmark.

It made my timeClient.update() come back empty, and then it just keep looping, and ate my batteries in less than 3 hours.

With this change, module just sleeps for another hour, and tries again.

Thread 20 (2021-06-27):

Home Assistant sensor config MQTT not retained and eventually sensors all become 'unavailable'

gitothy, 2021-06-27:
I've been seeing odd behaviour that all entities for my HIGrow show as _unavailable_ in Home Assistant after a period of time. I found this odd as the device is running from the mains and TIME_TO_SLEEP is at the default of 3 hours (10800 seconds).

I've managed to work out that the config entry to MQTT under topic homeassistant/sensor/Tgrow_HIGrow_macaddress isn't retained and seems to disappear at "some point".  I can see that my sensor had crashed on the latest occurrence of this issue and had been offline for 2 weeks while I was away.  I've just power cycled it and can see a new message on the broker but the sensors show as unavailable in HA.  Expected behaviour here would be that when the new data is pushed to MQTT and you're back running again.  Last time this happened there was no two week gap, although I can't remember exactly what happened other than that I had to restart the broker a few times to fix an issue that it didn't have the right write permissions to save it's database and log.

My workaround for whenever this happens is to republish the config using **TTGO-T-HIGrow-aut.py** which restores it in HA.  Must be a better way to deal with this though?

pesor, 2021-07-03:
Which MQTT broker are you using, as I have not seen this problem my self.

gitothy, 2021-07-06:
Mosquito in a docker, latest version

pesor, 2021-07-06:
I have experienced this my self.

Most times was in connection with broker Update or Home Assistant upgrade, but I have not seen it for the last 3 months.

I do not know what causes it, but yes, delete in Home Assistant, delete in sensors.yaml, return the Python Autodiscover program, and as you describe it All works again.

Actually the same have happened with the TASMOTA devices, where on had to follow same procedure to get the devices back in Home Assistant. Also I have not seen this for 3 months.

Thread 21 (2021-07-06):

MQTT Connection failure

JohnnyNegativity, 2021-07-06:
Hi, I have been following bearded tinkerer's instructions to get this setup with home assistant.

I have the mosquitto MQTT broker running in home assistant, working for multiple other devices.

When I configure the user variables and flash the board, it successfully connects to wifi but cannot reach the MQTT broker, giving the error below:

Sending message to topic: {"plant":{"Tgrow_HIGrow":"c44f337fc6e1","sensorname":"","date":"06-07","time":"15:46","sleep5Count":0,"bootCount":0,"lux":835.8333,"temp":26.3,"humid":42,"soil":65535,"soilTemp":0,"salt":0,"saltadvice":"needed","bat":100,"batcharge":"charging","batchargeDate":"06-07","daysOnBattery":0,"battvolt":2752,"battvoltage":4.879004,"pressure":0,"plantValveNo":1,"wifissid":"21BTG_NoT","rel":"4.3.2"}}
Attempting to connect to the MQTT broker: 192.168.1.100
[E][WiFiClient.cpp:258] connect(): socket error on fd 55, errno: 104, "Connection reset by peer"
MQTT connection failed! Error code = -2
Going to sleep... 300 sekunder

Any help would be much appreciated. Thanks!

pesor, 2021-07-06:
First thing that comes to mind is the broker port no.

I have a typo in the Connect issue, where 1883 is hard coded, even though the port is part of usersetting.

So if you are not using 1883, but another number this could be the reason.

Next is username and password, if you are using this check for typing error. Mixed case / uppercase / both.

//
Per

JohnnyNegativity, 2021-07-06:
Thanks very much for the quick response.

Indeed I am using a non-standard port and this has solved the issue.

Much appreciated!

elecoq129, 2021-07-22:
Hi Johnny,
As I have never experienced any issue with my envirnoment, like you described above, I will be very intereted to know what is your config? I am using a dedicated PC running Win10 + Unbuntu server (Oracle VM v. 6.1)  + HA and MQTT server (latest version). I have roughly 10 TTGO sensors connected to it using WiFi (WAN) connection. All is well.

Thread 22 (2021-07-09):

[Casing] Size-up hole + srew

FutureCow, 2021-07-09:
Really nice project, already using this to monitor some plants.
Also want to monitor some outdoor plants, so was looking at your caseing, nice!

But isn't it easier to make the hole on the side a bit bigger, so you can just connect the USB-C on the port?

pesor, 2021-07-09:
Actually, I have changed so that the Hole fits to a C-plug, will upload it latest sunday.

FutureCow, 2021-07-09:
Thanks for the quick reply, looking forward to it!

pesor, 2021-07-11:
Probably first monday or tuesday

FutureCow, 2021-07-14:
Case ready for sharing?

pesor, 2021-07-15:
As I am very busy at this moment, I have uploaded the casing workfiles to [casing ](https://tordenvejr.nu/casing.zip),

This is my latest workfiles, and you will find the C-plug cacing here.

// Per

pesor, 2021-07-21:
@FutureCow

Have you downloaded

FutureCow, 2021-08-25:
Yes, sorry for the late reply.
I can use the 3D printer next week, But wich is the file that you changed?
Cattleya.stl
ClosedBatteryCase.stl
Padron2.stl
Padron3.stl

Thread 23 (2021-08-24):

waterproof casing

garudaonekh, 2021-08-24:
hi,
what is the recommended method to make it usable outdoor?

pesor, 2021-08-24:
I do two things.

First I spray the modules with and isolation and protection enamel/polish, in order to avoid corrotion.

I use the Teslanol for this.

Second I seal the case where the module sticks out, I use silicone, which is made for aquariums, and then I put some on where the plug is on the casing, as it can make a small opening. I use a finger with a little silicone, and smear it on.

It is easy to take apart again, if needed, for a new battery etc.

garudaonekh, 2021-08-24:
I think a 1" pvc pipe is the cheapest solution but the problem is the bottom part. it is difficult to protect the part that stick out

garudaonekh, 2021-08-24:
![Uploading 16297998136296109717055170172881.jpg…]()

pesor, 2021-08-24:
Look at a previous issue, there is a link to my 3D print of cases.

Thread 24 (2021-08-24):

PIN left

garudaonekh, 2021-08-24:
hi, how many pins left? I want to add 6 channel relay.

pesor, 2021-08-24:
You can easy add an 6 channel relay, as you can use any IO pin on the module, and there is pin's enough free.

garudaonekh, 2021-08-24:
ok, thanks. let me try.

Closed 2021-08-24.

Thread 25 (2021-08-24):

Reliability of this TTGO version the original HiGrow

garudaonekh, 2021-08-24:
Hi,
I heard a lot of complain about the original HiGrow. Do you have any feedback on this TTGO version in term of its result and battery usage?

I have used several soil moisture sensors(analog capacitive) ranging from the 1$ low cost to 15$ from DF-Robot. I found DF-Robot to be more stable in its result and I need to ADS1115 with my esp32(ADC of Esp32 is bad, as far as I know) or it may be due to my limited knowledge on how to use it properly.

I plan to use it to manage small plot of land per sensor(1 sensor for 4x20meter row) with a few relay to manage the water.

Thanks;

pesor, 2021-08-24:
As I am out today, I will give a full answer tomorrow.

Concerning irrigation, I have made a system using mqtt and an ESP32 to control it All. This solution could be fine for your need.

It is in Alpha/Beta but I have been using it the whole summer in my Greenhouse controlling 2 separate water relays, based on the soil percentage. The ESP32 can control at least 10 relays, maybe more, as you only need 1 IO port per relay.

In it is also measurement of water delivered, so the amount of liters can be controlled.

I will give you access to the repo tomorrow when I an Home.

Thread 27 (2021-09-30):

Auto configuration script error

riddlecp, 2021-09-30:
Hi, running into an issue with the auto discover python script.  Have tried multiple python versions just to be sure.  Any thoughts?

`python3 TTGO-T-HiGrow-aut.py
Connected with result code 0
in on_message
Tgrow_HIGrow/fcf5c40cfb10 b'{"plant":{"Tgrow_HIGrow":"fcf5c40cfb10","sensorname":"driveway_lawn","date":"30-09","time":"10:03","sleep5Count":0,"bootCount":0,"lux":523.3333,"temp":27.8,"humid":59,"soil":1,"soilTemp":0,"salt":0,"saltadvice":"needed","bat":100,"batcharge":"charging","batchargeDate":"30-09","daysOnBattery":0,"battvolt":2768,"battvoltage":4.90737,"pressure":0,"plantValveNo":1,"wifissid":"-REDACTED-","rel":"4.3.2"}}'
in read_yaml
Traceback (most recent call last):
  File "TTGO-T-HiGrow-aut.py", line 210, in <module>
    client.loop_forever()
  File "/usr/local/lib/python3.6/site-packages/paho/mqtt/client.py", line 1779, in loop_forever
    rc = self.loop(timeout, max_packets)
  File "/usr/local/lib/python3.6/site-packages/paho/mqtt/client.py", line 1181, in loop
    rc = self.loop_read(max_packets)
  File "/usr/local/lib/python3.6/site-packages/paho/mqtt/client.py", line 1572, in loop_read
    rc = self._packet_read()
  File "/usr/local/lib/python3.6/site-packages/paho/mqtt/client.py", line 2310, in _packet_read
    rc = self._packet_handle()
  File "/usr/local/lib/python3.6/site-packages/paho/mqtt/client.py", line 2936, in _packet_handle
    return self._handle_publish()
  File "/usr/local/lib/python3.6/site-packages/paho/mqtt/client.py", line 3216, in _handle_publish
    self._handle_on_message(message)
  File "/usr/local/lib/python3.6/site-packages/paho/mqtt/client.py", line 3444, in _handle_on_message
    self.on_message(self, self._userdata, message)
  File "TTGO-T-HiGrow-aut.py", line 196, in on_message
    yaml_data = read_yaml_file(mac_id, name)
  File "TTGO-T-HiGrow-aut.py", line 36, in read_yaml_file
    line_mac_id = line_mac_id_arr[1]
IndexError: list index out of range
`

riddlecp, 2021-09-30:
This doesn't really make any sense to me, but it worked - change the line
`line_mac_id = line_mac_id_arr[1]`
to
`line_mac_id = line_mac_id_arr[0]`

pesor, 2021-09-30:
I look into it, how does your sensors.yaml look like.

//Per

riddlecp, 2021-09-30:
after changing that index value, it created fine apparently:

`# cat sensors.yaml`
`info: This file contains the MAC_ID of the sensors already registred for Autodiscover`
`info: You can reinitiate Autodiscover for a single MAC_ID, by removing it from the list, or you can initiate a full renewal of sensors to Autodiscover,`
`info: By removing all MAC_IDs below these comments lines`
`info: DO NOT REMOVE THESE FOUR INFO LINES.`

`mac_id: fcf5c40cfb10`
`name: driveway_lawn`

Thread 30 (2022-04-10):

Not using with Home Assistant

Ianszh, 2022-04-10:
Hello, I'd like to use this outside of Home Assistant (MQTT - Node-Red), I have some of the older versions with a 18650 battery and  DHT11's, I've set the necessary true and false in user-variables.h and  I'm receiving the MQTT messages in node-red, but there are some missing and strange values.
No data from the DHT11 and daysOnBattery: 19092.7 etc. could you give some advice please?

`"{"plant":{"Tgrow_HIGrow":"246f28af39e8","sensorname":"Chilli-1","date":"10-04","time":"17:31","sleep5Count":0,"bootCount":34,"lux":-2,"temp":null,"humid":null,"soil":65535,"soilTemp":0,"salt":0,"saltadvice":"needed","bat":-220,"batcharge":"","batchargeDate":"","daysOnBattery":19092.7,"battvolt":69,"battvoltage":0.12233,"pressure":0,"plantValveNo":1,"wifissid":"xxxxx","rel":"4.3.2"}}"`

pesor, 2022-04-10:
In the uservariable file there are a lot of variables, have you looked into this.

One set concerns the DHT11.

//
Per

Sendt fra min iPhone

Den 10. apr. 2022 kl. 17.35 skrev Ianszh ***@***.***>:

Hello, I'd like to use this outside of Home Assistant (MQTT - Node-Red), I have some of the older versions with a 18650 battery and DHT11's, I've set the necessary true and false in user-variables.h and I'm receiving the MQTT messages in node-red, but there are some missing and strange values.
No data from the DHT11 and daysOnBattery: 19092.7 etc. could you give some advice please?

"{"plant":{"Tgrow_HIGrow":"246f28af39e8","sensorname":"Chilli-1","date":"10-04","time":"17:31","sleep5Count":0,"bootCount":34,"lux":-2,"temp":null,"humid":null,"soil":65535,"soilTemp":0,"salt":0,"saltadvice":"needed","bat":-220,"batcharge":"","batchargeDate":"","daysOnBattery":19092.7,"battvolt":69,"battvoltage":0.12233,"pressure":0,"plantValveNo":1,"wifissid":"xxxxx","rel":"4.3.2"}}"

—
Reply to this email directly, view it on GitHub<https://github.com/pesor/TTGO-T-HIGrow/issues/30>, or unsubscribe<https://github.com/notifications/unsubscribe-auth/AAXXLJGY322TGRET23E4RXLVELYNPANCNFSM5TA7QEXA>.
You are receiving this because you are subscribed to this thread.Message ID: ***@***.***>

Ianszh, 2022-04-11:
Yes, I did look into the variables when setting up. any Idea about the daysOnBattery?

Also is there a setting where I can adjust the wake time?

pesor, 2022-04-19:
You can only assign the sleep time, see the WIKI to learn more.

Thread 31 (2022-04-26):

WiFi connected but no DHCP

TheCranston, 2022-04-26:
I'm not sure what happened other than I made a change to the sleep length and re-uploaded...

I see the esp32 connect to my WiFi access point, however I don't see a DHCP request going out.
The AP shows an association but no IP address.
The esp32 is "stuck" with this continuous error in the serial console:
```[xxxx][E][WiFiUdp.cpp:170] beginPacket(): could not get host from dns: 11```
where the [xxxx] is an ever increasing number.

I've tried using esptool.py to erase the SPI flash and start over thinking something got corrupted there.  No change in behaviour.
I'm thinking something is out of compatibility spec in the platform.io environment, but alas I'm lost there.  really just following BeardedTinker's video/docs on how to build the project.  It did auto update a bunch of libraries and maybe that's the issue.  Any help is apprecaited.

I've also tried fully ripping out VSC and platform.io and starting over.  Same result.  Not sure what is breaking.
pio core 5.2.5 home 3.4.1 with espressif 4.1.0

I know the WiFi is physically working as I went back to Arduino IDE and was able to get the http client example sketch to work just fine.

And some pause before submitting and a little google searching and I find a recommended adjustment:
```
#include <WiFi.h>
void setup() {
  Serial.begin(115200);
  WiFi.begin(); //Put ssid, passwd in here if needed
  WiFi.waitForConnectResult();
  Serial.println(WiFi.dnsIP());
  WiFi.config(WiFi.localIP(), WiFi.gatewayIP(), WiFi.subnetMask(), WiFi.dnsIP());
  delay(10);
  Serial.println(WiFi.dnsIP());
}
```
Tested locally and can confirm it works now.

townet01, 2022-05-03:
Is necessary to comment this:

 //WiFi.config(INADDR_NONE, INADDR_NONE, INADDR_NONE); // call is only a workaround for bug in WiFi class

TheCranston, 2022-05-03:
So @townet01 you are saying that commenting out the line has the same effect as what I found of changing
```
WiFi.config(INADDR_NONE, INADDR_NONE, INADDR_NONE);
```
to
```
WiFi.config(WiFi.localIP(), WiFi.gatewayIP(), WiFi.subnetMask(), WiFi.dnsIP());
```

Works just as well as
```
//WiFi.config(WiFi.localIP(), WiFi.gatewayIP(), WiFi.subnetMask(), WiFi.dnsIP());
```

correct?

townet01, 2022-05-03:
Yes is correct !
Try.

townet01, 2022-05-03:
Yes it's correct !

E.

TheCranston, 2022-05-03:
I can try it this upcoming weekend.  I’ll report results then.  Thanks

Sent from my iPhone

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

JonOve, 2022-05-16:
Connecting the board to wifi I see the router gives the subnet mask adress 255.255 etc. as an ipadress to the board.
Adding above mentioned line to "user-variables.h" does not solve the issue.
Any ideas?

TheCranston, 2022-05-16:
@JonOve can you provide logs of the DHCP request from your router?  The router *should* not be handing out 255.255.255.255 as an IP address or something else is very wrong.  The suggested edit is in the "connect-to-network.h" file right around line 7 in the "connectToNetwork()" function.

JonOve, 2022-05-16:
@TheCranston, thank you for your quick reply. I was not aware of a "connect-to-network.h" file. Will see if I can find that one and edit it as proposed.

JonOve, 2022-05-16:
@TheCranston, after the edit the board connected to the ssid properly with a correct ipadress. Many thanks for your support!

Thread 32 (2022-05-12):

not an issue, mqtt autodiscovery idea for ha

Maaciej, 2022-05-12:
Auto discovery is complicated, it is not working for me, I don't understand what it tries to do, so I played with code.
***************
save-configuration.h

new function
***********************************************
```
void mqttSetup(String identyfikator, String chipId, String uom = "x" )
{

  Serial.println("*****************************************" );

  const String topicStr_c = "homeassistant/sensor/" + device_name + "-" + chipId + "/" + identyfikator +"/config";
  const char* topic_c = topicStr_c.c_str();
  Serial.println(topic_c);

  StaticJsonDocument<1536> doc_c;
  JsonObject root = doc_c.to<JsonObject>();

  root["name"] = device_name +" "+ identyfikator;
  root["state_topic"] = "homeassistant/sensor/" + device_name + "-" + chipId  + "/status";
  root["value_template"] = "{{ value_json['" + identyfikator +"'] }}";
  if ( uom != "x" ) {
    root["unit_of_measurement"] = uom;
  }
//copy of existing sending code
// // Send to mqtt
  char buffer_c[1536];
  serializeJson(doc_c, buffer_c);

  Serial.print("Sending message to topic: ");
  if (logging) {
    writeFile(SPIFFS, "/error.log", "Sending message to topic: \n");
  }

  Serial.println(buffer_c);

  // Connect to mqtt broker
  Serial.print("Attempting to connect to the MQTT broker: ");
  if (logging) {
    writeFile(SPIFFS, "/error.log", "Attempting to connect to the MQTT broker! \n");
  }

  // Serial.println(broker);
  mqttCli

ent.setServer(broker, port);

  if (!mqttClient.connect(broker, mqttuser, mqttpass)) {
    if (logging) {
      writeFile(SPIFFS, "/error.log", "MQTT connection failed! \n");
    }

    Serial.print("MQTT connection failed! Error code = ");
    Serial.println(mqttClient.state());
    // goToDeepSleepFiveMinutes();
  }

  if (logging) {
    writeFile(SPIFFS, "/error.log", "You're connected to the MQTT broker! \n");
  }

  Serial.println("You're connected to the MQTT broker!");
  Serial.println();

  bool retained = true;

  if (mqttClient.publish(topic_c, buffer_c, retained)) {
    Serial.println("Message published successfully");
  } else {
    Serial.println("Error in Message, not published");
    // goToDeepSleepFiveMinutes();
  }
  Serial.println("*****************************************" );
  Serial.println();

}
```
*******************************************
called before making json for mqtt with measure values:
*********************************************
```
  Serial.println("chipId " + chipId); //existing line

  mqttSetup("daysOnBattery", chipId);
  mqttSetup("battvoltage", chipId, "V");
  mqttSetup("bat", chipId, "%");
  mqttSetup("lux", chipId, "lx");
  mqttSetup("humid", chipId, "%");
  mqttSetup("soil", chipId, "%");
  mqttSetup("salt", chipId);
  mqttSetup("temp", chipId, "°C");

const String topicStr = "homeassistant/sensor/" + device_name + "-" + chipId + "/status"; //existing line
```

And with this changes measurements show itself in home assistant for me:

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

still don't know how to make the measurements  to be possible to disable, I mean make them with unique entity_id

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

***************
And question,
it seems like there somewhere is log stored and other files, how to access them?
I thought there is web server, or it should be visible as a portable drive but I can't find.
Can anybody explain how to access log?

Maaciej, 2022-05-12:
one more thing, because it can matter
I changed original JSON to this, with one level structure:

```
StaticJsonDocument<1536> doc;
  // Set the values in the document
  // Device changes according to device placement
  JsonObject plant = doc.to<JsonObject>();

  // JsonObject plant = root.createNestedObject("sensor"); //CHANGE!!!!!
  plant[device_name] = chipId;
  plant["sensorname"] = plant_name;
  plant["date"] = config.date;
  plant["time"] = config.time;
  plant["batchargeDate"] = config.batchargeDate;
  plant["daysOnBattery"] = config.daysOnBattery;
  // plant["battvolt"] = config.batvolt; //nie
  plant["bat"] = config.bat;
  plant["battvoltage"] = config.batvoltage;
  plant["sleep5Count"] = config.sleep5no;
  plant["bootCount"] = config.bootno;
  // plant["batcharge"] = config.batcharge; //nie
  plant["lux"] = config.lux; //nie
  plant["temp"] = config.temp;
  plant["humid"] = config.humid;
  // plant["pressure"] = config.pressure;
  plant["soil"] = config.soil;
  // plant["soilTemp"] = config.soilTemp; //nie
  plant["salt"] = config.salt;
  // plant["saltadvice"] = config.saltadvice;//nie
  // plant["plantValveNo"] = plantValveNo; //nie
  // plant["wifissid"] = WiFi.SSID(); //nie
  plant["rel"] = config.rel;
```

with two level structure one have to change json templates to read measurements.

Maaciej, 2022-05-13:
entity_id solved.
Because there are lot of changes in the file, full content:

```
void mqttSetup(String identyfikator, String chipId, String uom = "x", String dc = "x" )
{

  Serial.println("*****************************************" );

  const String topicStr_c = "homeassistant/sensor/" + device_name + "-" + chipId + "/" + identyfikator +"/config";
  const char* topic_c = topicStr_c.c_str();
  Serial.println(topic_c);

  StaticJsonDocument<1536> doc_c;
  JsonObject root = doc_c.to<JsonObject>();

  root["name"] = device_name +" "+ identyfikator;

  if ( dc != "x" ) {
    root["device_class"] = dc;
  }

  root["unique_id"] = chipId +"-"+ identyfikator;
  root["state_topic"] = "homeassistant/sensor/" + device_name + "-" + chipId  + "/status";
  root["value_template"] = "{{ value_json['" + identyfikator +"'] }}";
  if ( uom != "x" ) {
    root["unit_of_measurement"] = uom;
  }

// // Send to mqtt
  char buffer_c[1536];
  serializeJson(doc_c, buffer_c);

  Serial.print("Sending message to topic: \n");
  if (logging) {
    writeFile(SPIFFS, "/error.log", "Sending message to topic: \n");
  }

  // Serial.println(buffer_c);
  serializeJsonPretty(doc_c, Serial);
  Serial.println();

  // Connect to mqtt broker
  Serial.print("Attempting to connect to the MQTT broker: ");
  if (logging) {
    writeFile(SPIFFS, "/error.log", "Attempting to connect to the MQTT broker! \n");
  }

  // Serial.println(broker);
  mqttClient.setServer(broker, port);

  if (!mqttClient.connect(broker, mqttuser, mqttpass)) {
    if (logging) {
      writeFile(SPIFFS, "/error.log", "MQTT connection failed! \n");
    }

    Serial.print("MQTT connection failed! Error code = ");
    Serial.println(mqttClient.state());
    // goToDeepSleepFiveMinutes();
  }

  if (logging) {
    writeFile(SPIFFS, "/error.log", "You're connected to the MQTT broker! \n");
  }

  Serial.println("You're connected to the MQTT broker!");
  Serial.println();

  bool retained = true;

  if (mqttClient.publish(topic_c, buffer_c, retained)) {
    Serial.println("Message published successfully");
  } else {
    Serial.println("Error in Message, not published");
    // goToDeepSleepFiveMinutes();
  }
  Serial.println("*****************************************" );
  Serial.println();

}

// Allocate a  JsonDocument
void saveConfiguration(const Config & config) {

  //  Serial.println(WiFi.macAddress());
  //  String stringMAC = WiFi.macAddress();
  //  stringMAC.replace(':', '_');

  byte mac[6];
  WiFi.macAddress(mac);

  //  String chipId = String(mac[0], HEX) + String(mac[1], HEX) + String(mac[2], HEX) + String(mac[3], HEX) + String(mac[4], HEX) + String(mac[5], HEX);
  String chipId = "";
  String HEXcheck = "";
  for (int i = 0; i <= 5; i++) {
    HEXcheck = String(mac[i], HEX);
    if (HEXcheck.length() == 1) {
      chipId = chipId + "0" + String(mac[i], HEX);
    } else {
      chipId = chipId + String(mac[i], HEX);
    }
  }
  Serial.println("chipId " + chipId);

  mqttSetup("daysOnBattery",  chipId, "x",  "duration");
  mqttSetup("battvoltage",    chipId, "V",  "voltage");
  mqttSetup("bat",            chipId, "%",  "battery");
  mqttSetup("lux",            chipId, "lx", "illuminance");
  mqttSetup("humid",          chipId, "%",  "humidity");
  mqttSetup("soil",           chipId, "%",  "humidity");
  mqttSetup("salt",           chipId, "x");
  mqttSetup("temp",           chipId, "°C", "temperature");

  const String topicStr = "homeassistant/sensor/" + device_name + "-" + chipId + "/status";
  const char* topic = topicStr.c_str();
  Serial.println(topic);
  Serial.println(ssid);

  StaticJsonDocument<1536> doc;
  // Set the values in the document
  // Device changes according to device placement
  JsonObject plant = doc.to<JsonObject>();
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
Maaciej, 2022-05-17:
> Is it the intention to replace the content of the file "save-configuration.h" with your code as mentioned above?

yes this whole save-configuration file content customized (unnecessary fields of json commented out and changed json structure) for my needs, with added mqtt autodiscovery for ha.
I guess you change your file to above and should see that ha will detect configured metrics.

JonOve, 2022-05-18:
Indeed, worked like a charm. Thanks a lot for the effort!

pesor, 2022-05-21:
I replaced the save-configuration.h with your content above, but I get this error, any advice:

Creating JSON document...
chipId 246f28b21b3c
*****************************************
homeassistant/sensor/Tgrow_HIGrow-246f28b21b3c/daysOnBattery/config
Sending message to topic:
{
  "name": "Tgrow_HIGrow daysOnBattery",
  "device_class": "duration",
  "unique_id": "246f28b21b3c-daysOnBattery",
  "state_topic": "homeassistant/sensor/Tgrow_HIGrow-246f28b21b3c/status",
  "value_template": "{{ value_json['daysOnBattery'] }}"
}
Attempting to connect to the MQTT broker: Guru Meditation Error: Core  1 panic'ed (Unhandled debug exception)
Debug exception reason: Stack canary watchpoint triggered (loopTask)
Core 1 register dump:
PC      : 0x40093994  PS      : 0x00060036  A0      : 0x4008e638  A1      : 0x3ffc8e20
A2      : 0x00000001  A3      : 0x3ffc8050  A4      : 0x3ffc8050  A5      : 0x00000001
A6      : 0x00060020  A7      : 0x00000000  A8      : 0x80086148  A9      : 0x3ffc8ec0
A10     : 0x3ff000e0  A11     : 0x00000001  A12     : 0x3ffbe9b8  A13     : 0x00000001
A14     : 0x00060023  A15     : 0x00000000  SAR     : 0x00000018  EXCCAUSE: 0x00000001
EXCVADDR: 0x00000000  LBEG    : 0x4000c2e0  LEND    : 0x4000c2f6  LCOUNT  : 0xffffffff

ELF file SHA256: 0000000000000000

Backtrace: 0x40093994:0x3ffc8e20 0x4008e635:0x3ffc8f00 0x40127f71:0x3ffc8f40 0x40128a8f:0x3ffc8f60 0x401282b9:0x3ffc8f90 0x4012846c:0x3ffc8fb0 0x4011f158:0x3ffc8ff0 0x400d4cc4:0x3ffc9010 0x400d45c6:0x3ffc9070 0x40164a79:0x3ffc90a0 0x400d835a:0x3ffc90c0 0x400d8542:0x3ffc9100 0x400d2401:0x3ffc9130 0x400d2765:0x3ffc9dd0 0x400d4167:0x3ffcac50 0x400db5ea:0x3ffcad80 0x40091282:0x3ffcada0

Rebooting...
ets Jun  8 2016 00:22:57

Maaciej, 2022-06-23:
> And question,
it seems like there somewhere is log stored and other files, how to access them?
I thought there is web server, or it should be visible as a portable drive but I can't find.
Can anybody explain how to access log?

files in question are:

```
Listing directory: /
  FILE: favicon.ico     SIZE: 13532
  FILE: index.html      SIZE: 482
  FILE: app.js.gz       SIZE: 198509
  FILE: batinfo.conf    SIZE: 21
  FILE: error.log       SIZE: 1342
  FILE: soil.conf       SIZE: 9
  FILE: name.conf       SIZE: 9
```
files with extension .conf are from the program, and unknown are the first three.
I suspect now they are from the original firmware.
They cannot be removed by "remove",
but I erased all files with `SPIFFS.format()`
and now have only new files:

```
  FILE: name.conf       SIZE: 9
  FILE: batinfo.conf    SIZE: 21
  FILE: soil.conf       SIZE: 9
```

elgansayer, 2023-02-18:
Hi, i found a few issues with the above. Mainly having a device and sensor names. So updated some, added some,.

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

https://github.com/elgansayer/TTGO-T-HIGrow/tree/feature/AutoDiscovery

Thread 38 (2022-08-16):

Unstable battery voltage measurements

Maaciej, 2022-08-16:
First readings of battery voltage were very unstable for me, not good for automating battery monitoring:

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

TL;DR
moving voltage reading to the beginning of  "setup"  did some improvement.
(I have 15 minutes deepsleep timer, to see in more interacive way what is going on)

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

All my changes are visible in commit 1629c91d2a13971aee2231d73eb6c70a7a6b3133 of
https://github.com/Maaciej/TTGO-T-HIGrow.git
in branch "doodling".

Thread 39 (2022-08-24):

Observation, possible issue with soil humidity measuring

Maaciej, 2022-08-24:
I noticed it before, readings of soil humidity increases in correlation with lowering battery level:

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

now made "laboratory test", with lilygrow in glass, first there was evaporating, I fixed it, put more water and covered glass

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

Then you can see twice, "voltage lower than 3,6V" => humidity rises.

Can it be software compensated? It is the question.
Does it have the same effect for different humidity levels?
More testing necessary.

And there comes another thing, reading depends of physical water level, I start to thinking that visible round connectors are for salt (it measure like resistance, but other way, in the air reading is 0, when I connected them with wire reading was like 3000), and the water level measurement is coming from painted surfaces, so calibration probably should take it into account and during water level calibration.

I made a test, the the water is always wet, but readings are changing during Liligo immersing into water, (and it not dry fast)

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

So I think the calibration description should be more specific about how to put it in water, and warn that first completely dry device should be checked, before going into water, or long drying will  be necessary.

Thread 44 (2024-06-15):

Code no longer fits the board

scottmclesly, 2024-06-15:
It looks like some libraries got updated over time and now the entire build does not fit ESP32 memory at least attempting to upload it via Arduino IDE.

Sketch too big; see https://support.arduino.cc/hc/en-us/articles/360013825179 for tips on reducing it.
text section exceeds available space in board

Compilation error: text section exceeds available space in board

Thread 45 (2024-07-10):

Still working on it? + some questions

erich74, 2024-07-10:
Hello,
I bought this board a while ago and only now have some time to work on it in order to water the plant in my office .
I also bought the Lilygo pump to hook up to the esp board (I'm planning to modify your code in order to trigger the pump when needed)

I came across BeardedTinker 2 videos on this board and your incredible work on it, thanks for that!
I just have a couple of questions:

1. Main question: are you still working on improving this code? You've been doing a great job. I do not have enough experience with the board and your code to say if it needs improvement or not, but I am just curious to know if you plan to improve it.

2. In BeardedTinker's second video there's an explanation about autodiscovery, the python stuff etc... I decided to leave it alone and just install the board and see what's going on.
I was really surprised to see that, without any change in the configuration.yaml of HA the main values of the board were already autodiscovered by HA ( see below screenshot of  default sensor card)
Does it mean autodiscovery, in your latest version, does work without the python thing?

3. Again in BeardedTinker's second video I see that the pressure is displayed on his dashboard. My board is the one without DHT sensor but with the BME one however in the mqtt status I do not have any pressure information, therefore it cannot be retrieved in HA (see below my mqtt status message). Do you have any explanation about this and how to get pressure info?

Thanks for your answers!
Eric

{
  "time": "09:59:31",
  "battvolt": 2687,
  "battvoltage": 4.544215,
  "bat": 100,
  "sleep5Count": 0,
  "bootCount": 12,
  "device_name": "Tgrow_HIGrow",
  "chipId": "083af2666f74",
  "sensorname": "HiGrow_Bureau",
  "date": "2024-07-10",
  "batchargeDate": "2024-07-10",
  "daysOnBattery": 0,
  "lux": 0.833333,
  "temp": 28.17,
  "humid": 55.58496,
  "soil": 65535,
  "salt": 0,
  "rel": "4.3.2mw",
  "millis": 4622,
  "RSSI": -63
}

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

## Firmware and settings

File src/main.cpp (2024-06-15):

#include <Arduino.h>
#include <Wire.h>
#include <BH1750.h>
#include <DHT.h>
#include <WiFi.h>
#include <NTPClient.h>
#include <ArduinoJson.h>
#include <SD.h>
#include <SPI.h>
#include <PubSubClient.h>
#include <Esp.h>
#include <time.h>
#include <TimeLib.h>

#include "driver/adc.h"
#include <esp_wifi.h>
#include <esp_bt.h>
#include "user-variables.h"
#include <18B20_class.h>
#include <Adafruit_BME280.h>

// Logfile on SPIFFS
#include "SPIFFS.h"

//           rel = "2.0;    // Implemented MAC id as unique identifier for the device, at same time device_name is frozen to Tgrow_HIGrow.
//           rel = "2.0.1"; // Implemented "_" + name index for sensor icon. Corrected missing leading zero in HEX address.
//           rel = "2.0.2"; // Implemented automatic search for feaseable WIFI SSID, and connect to this.
//           rel = "3.0.0"; // Implemented Home-Assistant MQTT Autodiscover.
//           rel = "3.0.1"; // Implemented Home-Assistant MQTT Autodiscover, Salt calibration and advice included.
//           rel = "3.0.2"; // DST switch over now works
//           rel = "3.0.3"; // Small error corrections
//           rel = "3.0.4"; // Adapting to HACS frontend card: Battery State Card
//           rel = "3.0.5"; // Implemented name of plant saved to SPIFFS
//           rel = "3.0.6"; // DST calculation was way wrong, corrected now.
//           rel = "4.0.0"; // Changed from Arduino EDI to VS Code - PlatformIO
//           rel = "4.0.1"; // Error correction in connect network
//           rel = "4.0.2"; // Organising subroutines, and functional code snippets.
//           rel = "4.0.3"; // Adding battery charged date, and days since last charge
//           rel = "4.0.4"; // Adding battery charged date, and days since last charge, added to SPIFFS so that data do not dissapear at reboot.
//           rel = "4.0.5"; // Merged change from @reenari, and corrected counter days since last change
//           rel = "4.0.6"; // Corrected counter days !!! AGAIN !!!
//           rel = "4.0.7"; // The plant name is now used as hostname, so it is more visible in your router
//           rel = "4.1.0"; // Possibility to add the external 18B20 temperature sensor
//           rel = "4.2.0"; // BME280 sensor implemented
//           rel = "4.2.2"; // For the Greenhouse auto watering, the plantValveNo have been introduced. (Greenhouse auto watering is in development)
//           rel = "4.2.3"; // Removed the battery day counter - for good, use BeardedTingers solution if you need it.
//           rel = "4.3.1"; // Finally the days since last charging works correctly.
const String rel = "4.3.2mw"; // Corrected an error in DST.

// mqtt constants
WiFiClient wifiClient;
PubSubClient mqttClient(wifiClient);

// Date calculator
unsigned long epochTime;
String battChargeEpoc;
unsigned long epochChargeTime;
float battChargeDateDivider = 86400;
float daysOnBattery;
unsigned long setupstart;

// Reboot counters
RTC_DATA_ATTR int bootCount = 0;
RTC_DATA_ATTR int sleep5no = 0;

// Voltage stabilization
// RTC_DATA_ATTR float voltage_previous_read = 0;

//Sensor bools
bool bme_found = false;

//json construct setup
struct Config
{
  String date;
  String time;
  int bootno;
  int sleep5no;
  float lux;
  float temp;
  float humid;
  float soil;
  float soilTemp;
  float salt;
  String saltadvice;
  float bat;
  String batcharge;
  String batchargeDate;
  float daysOnBattery;
  float batvolt;
  float batvolt_read;
  // float batvolt_prev;
  float batvoltage;
  float pressure;
  String rel;
};
Config config;

const int led = 13;

#define I2C_SDA 25
#define I2C_SCL 26
#define DHT_PIN 16
#define BAT_ADC 33
#define SALT_PIN 34
#define SOIL_PIN 32
#define BOOT_PIN 0
#define POWER_CTRL 4
#define USER_BUTTON 35
#define DS18B20_PIN 21

BH1750 lightMeter(0x23); //0x23
Adafruit_BME280 bmp;     //0x77

DHT dht(DHT_PIN, DHT_TYPE);
DS18B20 temp18B20(DS18B20_PIN);

WiFiUDP ntpUDP;
NTPClient timeClient(ntpUDP);
String formattedDate;
String dayStamp;
String timeStamp1;

// Start Subroutines

#include <file-management.h>
#include <go-to-deep-sleep.h>
#include <get-string-value.h>
#include <read-sensors.h>
#include <save-configuration.h>
#include <connect-to-network.h>
#include <read-batt-info.h>
#include <floatConv.h>

// void listAllFiles(){
 
//   File root = SPIFFS.open("/");
 
//   File file = root.openNextFile();
 
//   while(file){
 
//       Serial.print("FILE: ");
//       Serial.println(file.name());
 
//       file = root.openNextFile();
//   }
 
// }



void setup()
{
  setupstart = millis();//like 43
  //! Sensor power control pin , use deteced must set high
  pinMode(POWER_CTRL, OUTPUT);
  digitalWrite(POWER_CTRL, 1);
  delay(1000);

  

  Serial.begin(115200);
  Serial.println("Void Setup");

  uint16_t voltx = analogRead(BAT_ADC);//start of work no wifi fresh battery
  Serial.print("VOLTXXXXXXXX :");
  Serial.println(voltx);


#include <module-parameter-management.h>



  // Start WiFi and update time
  connectToNetwork();
  Serial.println(" ");
  Serial.println("Connected to network");
  if (logging)
  {
    writeFile(SPIFFS, "/error.log", "Connected to network \n");
  }



  Serial.println(WiFi.macAddress());
  Serial.println(WiFi.localIP());
  //  configTime(gmtOffset_sec, daylightOffset_sec, ntpServer);
  //  timeClient.setTimeOffset(7200);

  timeClient.setTimeOffset(gmtOffset_sec);
  while (!timeClient.update())
  {
    timeClient.forceUpdate();
  }

#include <time-management.h>
  //#include <battChargeDays.h>
  if (dht_found)
  {
    dht.begin();
  }
  else
  {
    Serial.println(F("Could not find a valid DHT sensor, check if there is one present on board!"));
  }

  bool wireOk = Wire.begin(I2C_SDA, I2C_SCL); // wire can not be initialized at beginng, the bus is busy
  if (wireOk)
  {
    Serial.println(F("Wire ok"));
    if (logging)
    {
      writeFile(SPIFFS, "/error.log", "Wire Begin OK! \n");
    }
  }
  else
  {
    Serial.println(F("Wire NOK"));
  }

  if (!bmp.begin())
  {
    Serial.println(F("Could not find a valid BMP280 sensor, check wiring!"));
    bme_found = false;
  }
  else
  {
    bme_found = true;
  }




  if (lightMeter.begin(BH1750::CONTINUOUS_HIGH_RES_MODE))
  {
    Serial.println(F("BH1750 Advanced begin"));
  }
  else
  {
    Serial.println(F("Error initialising BH1750"));
  }

  float luxRead = lightMeter.readLightLevel(); // 1st read seems to return 0 always
  Serial.print("lux first read is 0; ");
  Serial.println(luxRead);
  delay(2000);

  if (dht_found)
  {
    float t12 = dht.readTemperature(); // Read temperature as Fahrenheit then dht.readTemperature(true)
    config.temp = t12;
    delay(2000);
    float h12 = dht.readHumidity();
    config.humid = h12;
  }

  if (bme_found)
  {
    float bme_temp = bmp.readTemperature();
    config.temp = bme_temp;

    float bme_humid = bmp.readHumidity();
    config.humid = bme_humid;

    float bme_pressure = (bmp.readPressure() / 100.0F);
    config.pressure = bme_pressure;
  }

  uint16_t soil = readSoil();
  config.soil = soil;
  float soilTemp = readSoilTemp();
  config.soilTemp = soilTemp;

  uint32_t salt = readSalt();
  config.salt = salt;
  String advice;
  if (salt < 201)
  {
    advice = "needed";
  }
  else if (salt < 251)
  {
    advice = "low";
  }
  else if (salt < 351)
  {
    advice = "optimal";
  }
  else if (salt > 350)
  {
    advice = "too high";
  }
  //Serial.println(advice);
  config.saltadvice = advice;

  // Battery status, and charging status and days.
  float bat = readBattery(voltx);
  config.bat = bat;
  config.batcharge = "";
  Serial.print("Battery level: ");
  Serial.println(bat);
  if (bat > 110)
  {
    config.batcharge = "charging";
    SPIFFS.remove("/batinfo.conf");
    epochChargeTime = timeClient.getEpochTime();
    battChargeEpoc = String(epochChargeTime) + ":" + String(dayStamp);
    const char *batinfo_write = battChargeEpoc.c_str();
    writeFile(SPIFFS, "/batinfo.conf", batinfo_write);
    Serial.print("charging dayStamp = ");
    Serial.println(dayStamp);
    config.batchargeDate = dayStamp;
  }




 

// Serial.println("\n\n----Listing files before format----");
//   listAllFiles();
 
//   bool formatted = SPIFFS.format();
 
//   if(formatted){
//     Serial.println("\n\nSuccess formatting");
//   }else{
//     Serial.println("\n\nError formatting");
//   }
 
//   Serial.println("\n\n----Listing files after format----");
//   listAllFiles();

  Serial.print("Charge Epoc (time) = ");
  Serial.println(battChargeEpoc);
  unsigned long epochTime = timeClient.getEpochTime();
  Serial.print("Test Epoc = ");
  Serial.println(epochTime);
  epochChargeTime = battChargeEpoc.toInt();
  Serial.print("first time calculation = ");
  Serial.println(epochTime - epochChargeTime);
  float epochTimeFl = float(epochTime);
  float epochChargeTimeFl = float(epochChargeTime); 
  

  daysOnBattery = (epochTimeFl - epochChargeTimeFl) / battChargeDateDivider;
  daysOnBattery = truncate(daysOnBattery, 1);
  config.daysOnBattery = daysOnBattery;

  if (bat > 100)
  {
    config.bat = 100;
  }

  config.bootno = bootCount;

  luxRead = lightMeter.readLightLevel();
  Serial.print("lux ");
  Serial.println(luxRead);
  config.lux = luxRead;
  config.rel = rel;

  // Create JSON file
  // Serial.println(F("Creating JSON document..."));
  if (logging)
  {
    writeFile(SPIFFS, "/error.log", "Creating JSON document...! \n");
  }
  saveConfiguration(config);

  // Go to sleep
  //Increment boot number and print it every reboot
  ++bootCount;
  Serial.println("Boot number: " + String(bootCount));

  //Go to sleep now
  delay(1000);
  goToDeepSleep();
}

void loop()
{
}

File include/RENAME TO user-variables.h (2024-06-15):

// *******************************************************************************************************************************
// START userdefined data
// *******************************************************************************************************************************
#include <Arduino.h>
// Turn logging on/off - turn read logfile on/off, turn delete logfile on/off ---> default is false for all 3, otherwise it can cause battery drainage.
const bool  logging = false;
const bool  readLogfile = false;
const bool  deleteLogfile = false;
String readString; // do not change this variable

// Select DHT type on the module - supported are DHT11, DHT12, DHT22 -- Even if you do not have one, you have to uncomment one, as compilation else will fail.
//#define DHT_TYPE DHT11
#define DHT_TYPE DHT12
//#define DHT_TYPE DHT22

// Set to true if you have a DHT sensor on the board, and false if not
bool dht_found = false;

// Select if 18B20 soil temp sensor available, if available -->> set to true
const bool USE_18B20_TEMP_SENSOR = false;

// It is a really good thing to calibrate each unit for soil, first note the number when unit is on the table, the soil number is for zero humidity. Then place the unit up to the electronics into a glass of water, the number now is the 100% humidity.
// By doing this you will get the same readout for each unit. Replace the value below for the dry condition, and the 100% humid condition, and you are done.

// Soil defaults - change them to your calibration data
int soil_min = 1535;
int soil_max = 3300;
bool calibrate_soil = false;

//battery volt measured with multimetr, after disconecting from board, and value reported near end of work
float     bat_volt_low     = 3.024;
uint16_t  bat_reading_low  = 1551;
//battery volt measured with multimetr, after disconecting from board and value reported just after charging
float     bat_volt_high    = 4.12;
uint16_t  bat_reading_high = 2370;

// Salt/Fertilizer recommandation break points. You can change these according to your own calibration measurements.
int fertil_needed = 200;
int fertil_low = 201;
int fertil_opt = 251;
int fertil_high = 351;

// Give the sensor a plant name, change to true, upload sketch and then revert to false
const bool update_plant_name = false;
String plant_name = "Lilygo_01";

//If using the Greenhouse automatic watering repo, then assign a waterValveNo to the plant. 
int plantValveNo = 1;

// define your SSID's, and remember to fill out variable ssidArrNo with the number of your SSID's
String ssidArr[] = {"Enterprise-pro", "Enterprise_EXT", "Enterprise_EXTN", "Enterprise" };
int ssidArrNo = 4;

const char* ssid = ""; // no need to fill in
const char* password = "password";
const char* ntpServer = "pool.ntp.org";

// Off-sets for time, and summertime. each hour is 3.600 seconds.
const long  gmtOffset_sec = 3600;

// Device configuration and name setting
const String device_name = "Tgrow_HIGrow"; // Can be changed, but not necessary, as it will give no added value.

#define uS_TO_S_FACTOR 1000000ULL //Conversion factor for micro seconds to seconds
#define TIME_TO_SLEEP  10800       //Time ESP32 will go to sleep (in seconds)

const char broker[] = "192.168.1.64";
int        port     = 1883;
const char mqttuser[] = ""; //add eventual mqtt username
const char mqttpass[] = ""; //add eventual mqtt password
const char mqttprefix[] = "homeassistant/sensor/"

// *******************************************************************************************************************************
// END userdefined data
// *******************************************************************************************************************************

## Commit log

2020-11-21 Fix off-by-one SSID array access
    [main.cpp]
2020-12-05 Adding battery charged date and day count
2020-12-06 Adding battery charge info to SPIFFS
2020-12-23 remove unnesessary bme280 library, change wire initialization
2020-12-26 Merged change from @reenari, corrected cnt charge
    [main.cpp]
2020-12-29 Small error correction charge date count
    [main.cpp]
2020-12-30 Release 4.0.6 - counter days corrected
    [main.cpp]
2021-01-25 Casing for the module
    [TIGO-HIGrow-buttom-Master-magnetic-charge.stl, TIGO-HIGrow-lid-Master-magnetic-charge.stl, TIGO-HIGrow-master - magnetic-charging.FCStd]
2021-02-10 Release 4.1.0 - add external TTGO soil temp sensor
2021-03-03 New better cases
    [ClosedBatteryCase.FCStd, ClosedBatteryCase.stl, ClosedBatterySoilSensorCase.FCStd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]
2021-03-03 New case images
2021-03-04 Minor adjustments
    [ClosedBatteryCase.FCStd]
2021-03-05 v4.3.1 - On battery days now correct
    [main.cpp]
2021-04-03 Rel. 4.3.2 -- Correct DST error
    [main.cpp]
2021-05-26 Update main.cpp to use proper casing for Esp.h
    including "ESP.h" might work on case insensitive filesystems, but since the file is actually called Esp.h it fails on case sensitive file systems.
    [main.cpp]
2022-08-16 Bundle of changes, MQTT autodiscovery, battery voltage reading
    Changes made to run program and then some customisations.
    List of things done:
    - correction of WiFi connection
    - added service of wake button
    - changed time/date formatting
    - changed data reporting
    - added mqtt autodiscovering sensors, with types and values customisation
    - changed mqtt paths
    - fixed sleep5no
    - added measuring of rssi
    - changed battery voltage moment of measure
    - changed voltage calculations with calibration
    - added code to clear file system (to clean files from original firmware), DISABLED
    - test of private config file with gitignore, with example to use in github repository, testing idea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
    [RENAME TO user-variables.h, main.cpp]
